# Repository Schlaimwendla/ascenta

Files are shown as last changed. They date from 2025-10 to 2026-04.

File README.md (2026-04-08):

# 🦾👓 Ascenta – Guiding your Vision  

Welcome to **Ascenta** – a smart glasses project designed to **support blind and visually impaired people** in their daily lives.  
This is our **diploma thesis** project, powered by the **Arduino Nicla Vision board** and connected to a mobile app for seamless interaction.  

---

## 🌟 Project Idea  
Ascenta aims to make the world more accessible by combining **computer vision**, **edge AI**, and **wearable technology**:  

- 👓 **Smart Glasses** equipped with the **Nicla Vision** board  
- 📱 **Mobile App** connection for additional features and user control  
- 🧭 Guidance and assistance in daily life activities  
- ❤️ Designed with empathy and inclusivity at its core  

---

## 🛠️ Tech Stack
- **Hardware:** Arduino Nicla Vision (Edge AI, camera, sensors)  
- **Software:** MicroPython / Arduino IDE / Android App  
- **Connectivity:** WiFi - TCP for glasses ↔ app communication  
- **Features in progress:**  
  - Navigation hints  
  - Daily reminders & assistance via app  

---

## 🚀 Vision  
We believe technology should **remove barriers** – not create them.  
With Ascenta, our goal is to bring **independence, safety, and confidence** to visually impaired individuals.  

---

## 📲 About the App  
The companion app serves as a **hub for communication** between the smart glasses and the user:  
- Live feedback  
- Configurable guidance modes  
- Daily assistant (plans, reminders, etc.)  

---

## 📌 Current Status  
Fully finished App and working functionality between App and Glasses

---

## 💡 Why “Ascenta”?  
The name comes from **"ascent"**, symbolizing **rising above limitations**, and **"sentience"**, reflecting **intelligent guidance**.  
Together: **Ascenta – Guiding your Vision**.  

---

## 🤝 Contributing  
This is part of our diploma thesis, but feedback, ideas, and positive vibes are always welcome ✨  

---

## 🏷️ Hashtag  
#ascenta #guidingyourvision #smartglasses #niclavision #diplomarbeit  

---

👓💙 *Ascenta – Guiding your Vision*

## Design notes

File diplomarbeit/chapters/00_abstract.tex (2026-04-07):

% !TEX root = ../main.tex
\cleardoublepage
\chapter*{Abstract}
\markboth{Abstract}{Abstract}
\addcontentsline{toc}{chapter}{Abstract}

This diploma thesis details the development of ``Ascenta'', an intelligent assistive wearable designed to support visually impaired individuals. Given the challenges of navigating complex urban environments, the project aims to create an affordable solution using artificial intelligence to provide information about the user's social surroundings.

The technical framework utilizes the Arduino Nicla Vision microcontroller. The firmware implements the \textbf{F}aster \textbf{O}bjects, \textbf{M}ore \textbf{O}bjects (FOMO) architecture for efficient on-device face detection. For user interaction, a local and privacy-oriented voice recognition system was developed using the Vosk engine within a custom Android application. Communication is established via an optimized TCP protocol to ensure low-latency data streaming between the wearable and the mobile device.

The current implementation successfully recognizes faces within the field of view and determines proximity using Time-of-Flight sensors. The results demonstrate the efficiency of the decentralized architecture and provide a solid foundation for future development of general obstacle detection models.

\cleardoublepage
\chapter*{Kurzfassung}
\markboth{Kurzfassung}{Kurzfassung}
\addcontentsline{toc}{chapter}{Kurzfassung}

Die vorliegende Diplomarbeit dokumentiert die Entwicklung von \glqq Ascenta\grqq, einer intelligenten Assistenzbrille zur Unterstützung sehbeeinträchtigter Personen im Alltag. Angesichts der Komplexität moderner urbaner Umgebungen besteht das Ziel des Projekts in der Realisierung eines kostengünstigen Wearables, das mittels künstlicher Intelligenz Informationen über das soziale Umfeld liefert.

Die technische Umsetzung basiert auf dem Arduino Nicla Vision Mikrocontroller. Die Firmware nutzt die FOMO-Architektur (\textbf{F}aster \textbf{O}bjects, \textbf{M}ore \textbf{O}bjects) zur effizienten On-Device-Gesichtserkennung. Zur Interaktion wurde eine lokale, datenschutzkonforme Sprachverarbeitung auf Basis der Vosk-Engine in einer Android-Applikation implementiert. Die Kommunikation erfolgt über ein optimiertes TCP-Protokoll, um minimale Latenzzeiten beim Datenstreaming zwischen der Brille und dem Smartphone zu gewährleisten.

Das realisierte System ist in der Lage, Personen im Sichtfeld zu identifizieren und die Distanz mittels Time-of-Flight-Sensorik zu bestimmen. Die Ergebnisse belegen die Funktionalität der dezentralen Architektur und bilden die Grundlage für zukünftige Erweiterungen zur allgemeinen Hinderniserkennung.

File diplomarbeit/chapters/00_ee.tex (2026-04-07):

% !TEX root = ../main.tex
\chapter*{Eidesstattliche Erklärung}

\begingroup 
\linespread{1}\selectfont

Es wird an Eides statt erklärt, dass die vorliegende Diplomarbeit selbstständig und ohne fremde Hilfe verfasst, andere als angegebene Quellen und Hilfsmittel nicht direkt benutzt und die benutzten Quellen wörtlich und inhaltlich entnommenen Stellen als solche erkenntlich gemacht wurden.

\vspace{1.5cm}

\noindent
\begin{tabular}{@{}p{5.5cm} p{1cm} p{8.5cm}@{}}
\begin{tabular}{@{}l@{}}
    Braunau, 11.02.2026 \\
    \makebox[5.5cm]{\dotfill} \\
    \small Ort und Datum
\end{tabular} 
& & 
\begin{tabular}{c}
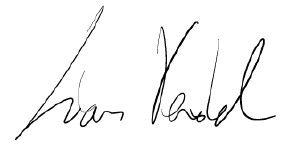
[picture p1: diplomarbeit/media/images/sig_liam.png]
    \smash{\raisebox{-0.4cm}{}} \\
    \makebox[8.5cm]{\dotfill} \\
    \small Liam Vendel
\end{tabular} \\[2.5cm]

\begin{tabular}{@{}l@{}}
    Braunau, 11.02.2026 \\
    \makebox[5.5cm]{\dotfill} \\
    \small Ort und Datum
\end{tabular} 
& & 
\begin{tabular}{c}
    \smash{\raisebox{-0.2cm}{}} \\
    \makebox[8.5cm]{\dotfill} \\
    \small Fabian Lindlbauer
\end{tabular} \\[2.5cm]

\begin{tabular}{@{}l@{}}
    Braunau, 11.02.2026 \\
    \makebox[5.5cm]{\dotfill} \\
    \small Ort und Datum
\end{tabular} 
& & 
\begin{tabular}{c}
    \smash{\raisebox{-0.2cm}{\hspace{-1cm}}} \\
    \makebox[8.5cm]{\dotfill} \\
    \small Manuel Zauner
\end{tabular}
\end{tabular}
\endgroup

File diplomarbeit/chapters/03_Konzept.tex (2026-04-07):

% !TEX root = ../main.tex
\chapter{Konzept}
Dieses Kapitel beschreibt die Architektur zum finalen Konzept des Assistenzsystems \glqq Ascenta\grqq. Es liefert einen detaillierten Gesamtüberblick über das funktionale Zusammenwirken der Teilsysteme und definiert die logischen Verantwortlichkeiten der einzelnen Komponentrn.

\section{Gesamtüberblick und Systeminteraktion}
Das System basiert konzeptionell auf einer dezentralen \glqq Split-Brain\grqq-Architektur, die die Gesamtarbeitslast strategisch auf zwei physisch getrennte, aber logisch eng vernetzte Knotenpunkte aufteilt. Das übergeordnete Ziel dieses Ansatzes ist es, die Hardware direkt am Kopf des Nutzers so leicht, energieeffizient und unauffällig wie möglich zu gestalten. Daher lagert die Architektur die ressourcenintensive Datenverarbeitung und komplexe Entscheidungslogik gezielt auf das ohnehin vorhandene Smartphone des Nutzers aus

Die Interaktion im Gesamtsystem wird durch diese Zweiteilung definiert:
\begin{itemize}
    \item \textbf{Die smarte Brille (Edge-Device):} Sie fungiert in diesem Konstrukt als spezialisierter Sensor-Satellit. Ihre Hauptaufgabe ist die kontinuierliche Erfassung der Umgebungsdaten (visuell, auditiv, räumlich) und die unmittelbare, latenzarme Vorverarbeitung direkt an der Datenquelle (Edge-AI). Anstatt rohe Videoströme zu senden, extrahiert sie lediglich relevante Metadaten und streamt diese bandbreitenschonend an das mobile Endgerät.
    \item \textbf{Das Smartphone (Host-Device):} Es übernimmt die Rolle des leistungsstarken Hauptrechenzentrums. Hier laufen die asynchronen Datenströme der Brille zusammen. Das System fusioniert die eingehenden Sensordaten, verarbeitet und analysiert die Benutzereingaben über Natural Language Processing (NLP) und führt die finale Kontextbewertung durch. Basierend auf dieser Auswertung generiert das Smartphone das situativ passende akustische Feedback.
\end{itemize}

Der detaillierte Informationsfluss zwischen diesen Komponenten wird in den folgenden Abschnitten anhand der spezifischen Datenflussdiagramme für die Use Cases visualisiert (siehe Abbildungen \ref{fig:flow_use_case_a} und \ref{fig:flow_use_case_b}).

\section{Datenfluss der Anwendungsszenarien}
Um das theoretische Zusammenwirken zwischen der Edge-Hardware (Brille) und der zentralen Logik (Smartphone) zu verdeutlichen, wird im Folgenden der Datenfluss für die definierten Kernszenarien (siehe Kapitel \ref{ch:02_use_cases}) dargestellt. Diese Diagramme zeigen die kaskadierende Verarbeitung von der Sensorerfassung bis zur Nutzerinteraktion.

\subsection{Datenfluss zur Kollisionsvermeidung}
Im Szenario der Hinderniserkennung (Use Case A) liegt der Fokus auf minimaler Latenz. Wie in Abbildung \ref{fig:flow_use_case_a} dargestellt, übernimmt die Brille die Vorfilterung der Bilddaten mittels FOMO. Nur wenn eine relevante Entität erkannt wird, erfolgt die Übertragung der Koordinaten und Distanzwerte an das Smartphone, welches die akustische Warnung auslöst.

\begin{figure}[htbp]
    \centering
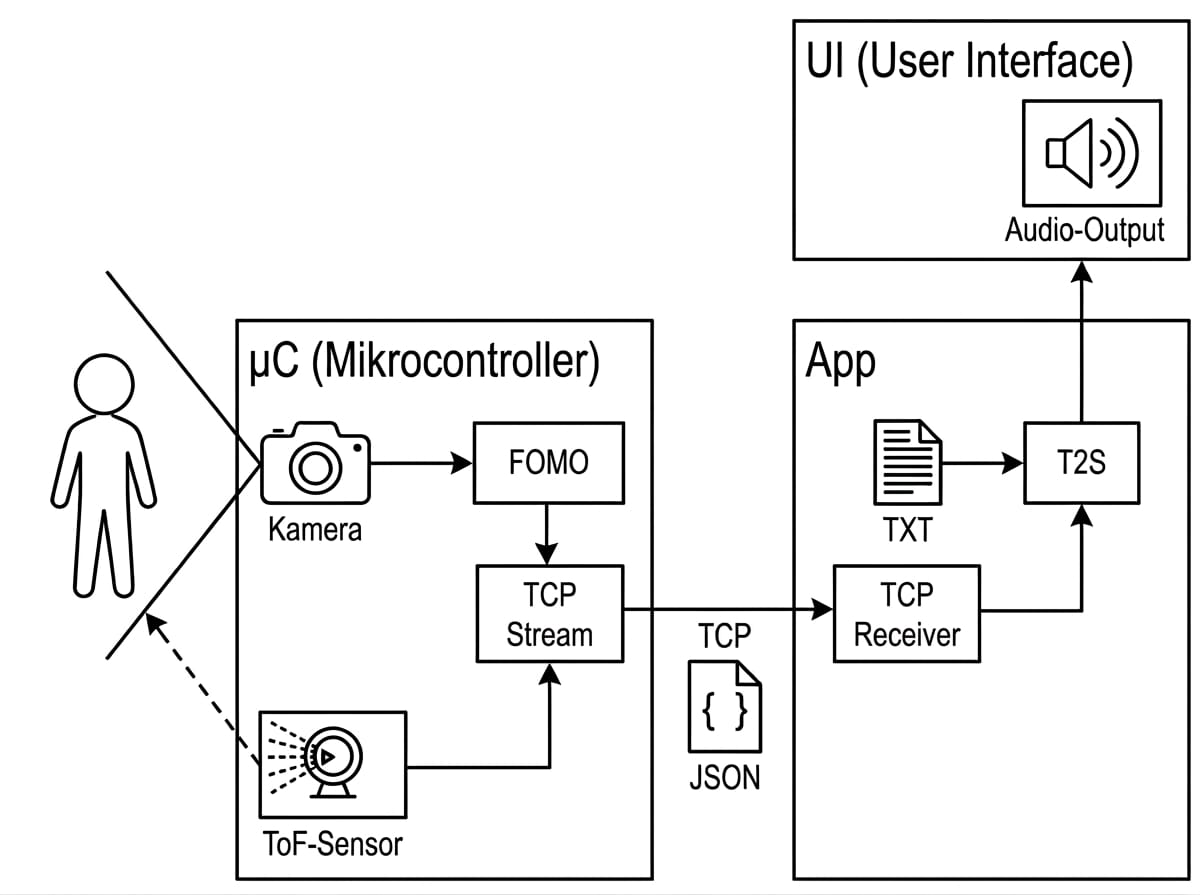
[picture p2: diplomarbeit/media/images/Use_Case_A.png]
    
    \caption{Datenflussdiagramm für Use Case A: Automatische Personenerkennung}
    \label{fig:flow_use_case_a}
\end{figure}

\subsection{Datenfluss der aktiven Umgebungsabfrage}
Bei der gezielten Abfrage durch den Nutzer (Use Case B) wird der Datenstrom um eine auditive Komponente erweitert. Abbildung \ref{fig:flow_use_case_b} zeigt den hybriden Stream: Während die visuellen Daten weiterhin im Hintergrund analysiert werden, wird der Sprachbefehl des Nutzers parallel an die lokale Vosk-Engine zur Interpretation weitergeleitet.

\begin{figure}[htbp]
    \centering
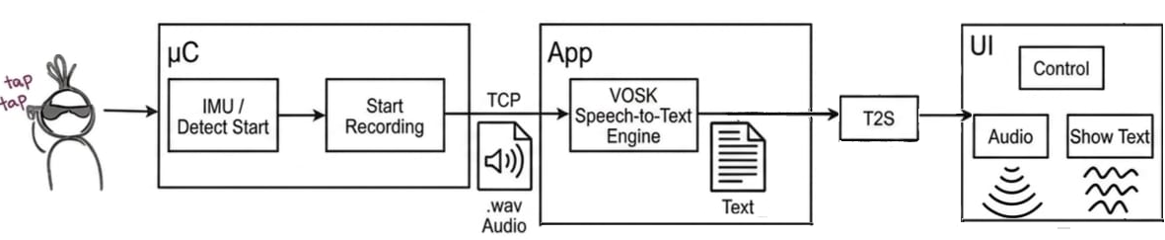
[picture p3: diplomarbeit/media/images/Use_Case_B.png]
    
    \caption{Datenflussdiagramm für Use Case B: Sprachgesteuerte Interaktion}
    \label{fig:flow_use_case_b}
\end{figure}

Die Trennung dieser Pfade stellt sicher, dass zeitkritische Warnungen nicht durch die komplexere Sprachverarbeitung blockiert werden.

\section{Komponenten}
\label{sec:komponenten}
Um den zuvor beschriebenen Datenfluss zu realisieren, setzt sich das Gesamtsystem aus drei wesentlichen logischen Bausteinen zusammen. Diese Säulen sind stark voneinander abhängig und wurden parallel konzipiert, um einen reibungslosen Betriebsablauf zu gewährleisten:

\begin{enumerate}
    \item \textbf{Die physische Struktur (Mechanik und Gehäuse):} Sie bildet das ergonomische Fundament. Sie muss die gesamte Elektronik sicher und unauffällig aufnehmen, eine exakte Ausrichtung der Sensorik garantieren und gleichzeitig die Gewichtsbalance für den Dauereinsatz sicherstellen.
    \item \textbf{Die elektronische Hardware (Sensorik und Energie):} Sie umfasst die physischen Schnittstellen zur realen Welt, primär den Mikrocontroller zur Datenerfassung sowie das autarke Akkumanagement zur mobilen Stromversorgung.
    \item \textbf{Das Software-Ökosystem (Intelligenz und Netzwerk):} Es ist das digitale Bindeglied, welches die rohen Hardware-Signale in verwertbare Informationen übersetzt. Es regelt die asynchrone Kommunikation und beinhaltet die trainierten neuronalen Netze zur Objekt- und Spracherkennung.
\end{enumerate}

\subsection{Software-Ökosystem und Netzwerkkonzept}
\label{sec:konzept_software}
Die Softwarearchitektur teilt sich in die Firmware des Mikrocontrollers und die mobile Applikation. Die Firmware (MicroPython) verantwortet die hardwarenahe Sensorsteuerung und eine erste Datenreduktion (Edge AI mittels FOMO). Die Android-Applikation (Kotlin) dient als unsichtbares Interface (reine Hintergrund-Applikation) und integriert komplexe Algorithmen wie die Offline-Spracherkennung (Vosk) zur auditiven Interaktion.

Der Kern des Konzepts liegt in der asynchronen, herstellerunabhängigen Interaktion zwischen der Brille (Sensorik), dem Kommunikationskanal (WiFi-TCP) und dem Smartphone (Logik und Feedback).

\subsection{Hardware und Elektronik}
\label{sec:konzept_elektronik}

Das hardwareseitige Konzept fokussiert die autonome Energieversorgung sowie eine intuitive Nutzersteuerung des Systems. Die Integration von zwei kompakten LiPo-Akkus mit einer Kapazität von jeweils 620 mAh ermöglicht eine mobile und besonders schlanke Bauweise. Diese Dimensionierung wahrt konzeptionell eine präzise Balance zwischen einem minimalen Platzbedarf und der notwendigen Energie für den Betrieb der KI-Modelle. Durch diesen Aufbau verfügt das System trotz der leichten Bauweise über genügend Leistungsreserven, um sowohl die kontinuierliche Verarbeitung der Sensordaten als auch die Ansteuerung der optischen Rückmeldung zuverlässig zu gewährleisten. Damit entsteht die hardwareseitige Grundlage für ein System, das den Anforderungen an Portabilität und Funktionalität gleichermaßen entspricht.

Zur Steuerung der Hardware nutzt das Konzept einen vibrationsbasierten Sensor als zentrales Bedienelement, welches die direkte Kontrolle über verschiedene Interaktionsmuster ermöglicht. Anstatt eines physischen Tasters detektiert dieser Sensor Klopfzeichen oder Erschütterungen am Gehäuse und wandelt diese in Steuerbefehle um:
\begin{itemize}
    \item \textbf{Systemaktivierung:} Eine einfache Betätigung schaltet das Nicla Vision Modul ein. Diese Hardware-Trennung schont die Kapazität der Akkus in Ruhephasen maßgeblich.
    \item \textbf{Sprachsuche:} Ein schnelles, zweimaliges Drücken (Double-Click) aktiviert die Audioaufnahme, um die Umgebung per Sprachbefehl nach einem bestimmten Gegenstand zu durchsuchen.
\end{itemize}

Um diese sprachgesteuerte Suchfunktion im Alltag praktikabel zu gestalten, sieht der theoretische Entwurf vor, das zugrundeliegende neuronale Netz auf eine Vielzahl von alltagsgebräuchlichen Objekten zu trainieren. Das Modell soll diese Gegenstände im aufgenommenen Bild anschließend zuverlässig identifizieren und lokalisieren.

\subsection{Mechanik und Gehäusedesign}
Im Rahmen der Konzeptphase wurden die grundlegenden Anforderungen und Zielsetzungen für die zu entwickelnde Brille definiert. Ein zentraler Aspekt bestand darin, die notwendige Elektronik unterzubringen, ohne dabei Funktionalität, Tragekomfort und Design zu vernachlässigen.

Der Aufbau des Modells besteht, wie bei herkömmlichen Brillen, aus zwei Brillenbügeln, einem Rahmen und zwei Gläsern als Abdeckung. Letztere sind nicht transparent und decken den Innenraum des Rahmens ab, in welchem die Elektronik verstaut ist.

Der Rahmen weist ein ergonomisches Design auf, das gut an der Stirn und überhalb der Augen anliegt. Nasenpads sorgen zusätzlich für ein angenehmes Sitzen auf der Nase. Die Bügel schließen bündig am Rahmen ab und sind über einen Scharniermechanismus mit diesem verbunden. Ihre ergonomische Form verläuft zunächst leicht nach außen, um im Schläfenbereich ausreichend Platz zu bieten, und verjüngt sich dann schräg nach innen, um hinter dem Ohr sicheren Halt zu gewährleisten. Auf diese Weise umschließt die Brille den Kopf des Benutzers und sorgt für einen stabilen Sitz.

\begin{figure}[H]
    \centering
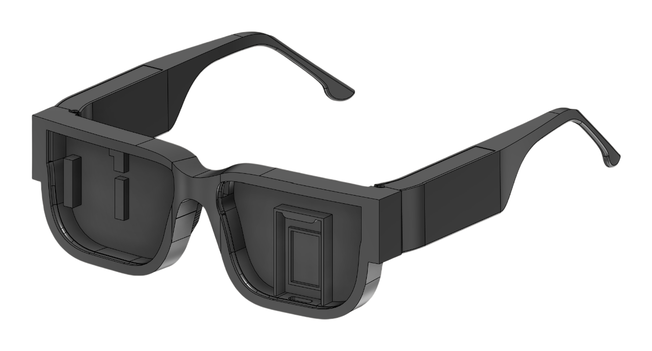
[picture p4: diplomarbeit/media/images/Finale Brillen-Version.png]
    
    \caption{Gesamtansicht der Brille}
    \label{fig:Gesamtansicht der Brille}
\end{figure}

Innerhalb des Rahmens befindet sich links eine Halterung für den Mikrocontroller und rechts eine Halterung für das Lademodul inklusive USB-C-Öffnung. \newline
Die Elektronik wird zusätzlich von den beiden Gläsern in ihrer Position gehalten.

\begin{figure}[H]
    \centering
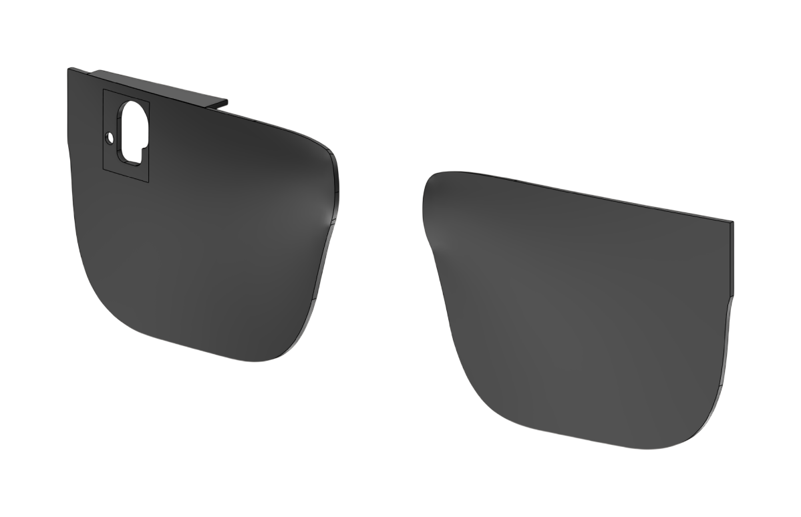
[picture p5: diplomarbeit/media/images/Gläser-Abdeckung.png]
    
    \caption{Gläser-Abdeckung}
    \label{fig:Gläser-Abdeckung}
\end{figure}

In jedem Bügel ist ein Akku untergebracht, der durch eine Abdeckung verborgen wird. Diese lässt sich einfach auf- und zuschieben.

Unterhalb der rechten Ecke des Rahmens befindet sich ein Schalter zum Ein- und Ausschalten der Brille.

Der Scharniermechanismus hält Rahmen und Bügel über einen von oben eingesetzten Pin zusammen und ermöglicht, dass die Brille auf beiden Seiten eingeklappt werden kann.

Durch den 3D-Druck ist die Brille leicht und modular aufgebaut. Alle Bauteile lassen sich einzeln demontieren und wieder zusammenfügen.

\section{Interaktionen}
Die Interaktion zwischen den Systemkomponenten und dem Nutzer verläuft in einem kontinuierlichen Kreislauf, der als asynchroner kaskadierender Prozess aufgebaut ist:

\begin{enumerate}
    \item \textbf{Eingabe-Trigger (Nutzer):} Der Prozess wird durch physisches Doppel-tippen an der Brille initiiert. Dieser Hardware-Interrupt triggert die Audioaufnahme.
    \item \textbf{Lokale Vorverarbeitung \& Edge-AI (Brille):} Das Nicla Vision erfasst Kamera-Frames und Audiodaten. Parallel läuft ein ressourcensparendes Edge-AI-Modell (FOMO) direkt auf dem Mikrocontroller. Es lokalisiert Gesichter oder vordefinierte Objektklassen im Kamerabild und übergibt die Koordinaten an die Vorverarbeitungseinheit.
    \item \textbf{Paketierung und WiFi-Stream:} Der Mikrocontroller paketiert die Sensorrohdaten (Audio-Chunks), die Distanzwerte (ToF-Sensor) und die KI-Koordinaten. Diese Daten werden asynchron in einen TCP-Stream geschrieben und über das lokale WiFi-Netzwerk gesendet.
    \item \textbf{Zentrale Logik \& Datenfusion (Smartphone):} Ein TCP-Socket-Server auf der Android-Applikation empfängt den Datenstrom. Die zentrale Steuerung fusioniert die Rohdaten und nutzt die ToF-Werte, um die relativen Distanzen der ermittelten KI-Koordinaten zu berechnen.
    \item \textbf{Kontextanalyse und Sprachverarbeitung:} Der Audiodatenstrom wird an die Offline-Spracherkennungs-Engine (Vosk) weitergeleitet, die den Sprachbefehl des Nutzers (z.\,B. \glqq Befindet sich jemand vor mir?\grqq) in Text umwandelt. Die Entscheidungslogik gleicht den Sprachbefehl anschließend mit den fusionierten Sensordaten ab.
    \item \textbf{Akustisches Feedback (Ausgabe):} Basierend auf der Analyse generiert das System ein Feedback. Es besteht entweder aus synthetisierter Sprache via Text-to-Speech (z.\,B. \glqq Person in einem Meter Entfernung erkannt\grqq) oder aus Signaltönen. Die Ausgabe erfolgt diskret über den Lautsprecher oder Kopfhörer des Smartphones.
\end{enumerate}

\section{Technisches Design}
Da das System mittels Kamera und Mikrofon sensible Umgebungsdaten erfasst, ist ein striktes Sicherheitskonzept integraler Bestandteil des Entwurfs. Das Konzept verfolgt hierbei den Ansatz des \textit{Privacy-by-Design}. Dies bedeutet, dass der Datenschutz nicht nachträglich aufgesetzt, sondern bereits in der fundamentalen Architektur als Standard verankert ist, indem Datenvermeidung und Offline-Verarbeitung strukturell priorisiert werden.

\subsection{Lokale Datenverarbeitung und Souveränität}
Im Gegensatz zu kommerziellen Smart-Glasses verzichtet \glqq Ascenta\grqq\ konsequent auf Cloud-Schnittstellen für die Kernfunktionen. Die Objekterkennung (FOMO) findet direkt auf dem Mikrocontroller statt, während die Spracherkennung (Vosk) lokal auf dem Android-Endgerät ausgeführt wird. Dies stellt sicher, dass zu keinem Zeitpunkt Videostreams oder private Audiodaten an externe Server übertragen werden. Die Datenhoheit verbleibt vollständig auf der Hardware des Nutzers.

\subsection{Absicherung der Netzwerkschnittstellen}
Durch den Verzicht auf das verbindungslose UDP und den Einsatz des verbindungsorientierten TCP wird die Stabilität der Sitzung erhöht. Da das System in einem lokalen Netzwerk operiert, ist die Angriffsfläche minimiert. Nach dem erfolgreichen Austausch der WLAN-Credentials über BLE wird dieser Kanal für weitere Datenübertragungen geschlossen. Das System nutzt die asynchrone TCP-Struktur, um Telemetrie und Binärdaten klar voneinander zu trennen. Das zugehörige Anwendungsprotokoll stellt jedem Binärpaket einen definierten Präfix inklusive der genauen Byte-Größe voran. Dies verhindert eine Fehlinterpretation von Datenpaketen (Cross-Talk) auf Softwareebene zuverlässig. Die lokale Verschlüsselung des WLAN-Access-Points sorgt zusätzlich dafür, dass Dritte den Datenstrom nicht passiv mitschneiden können.

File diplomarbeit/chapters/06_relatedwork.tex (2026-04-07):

% !TEX root = ../main.tex
\chapter{Verwandte Arbeiten}
\label{ch:related_work}

Dieses Kapitel ordnet das Projekt \glqq Ascenta\grqq\ in das Feld bestehender technischer Lösungen ein und zeigt die unterschiedlichen konzeptionellen Ansätze auf.

\section{Klassische Mobilitätshilfen}
Der weiße Langstock dient der taktilen Erfassung von Bodenhindernissen und Stufen. \glqq Ascenta\grqq\ ist als komplementäres System konzipiert, das durch den Einsatz von Time-of-Flight-Sensorik zusätzliche Informationen über den Raum oberhalb der Gürtellinie liefert, ohne die Funktion des Langstocks zu ersetzen

\section{Smartphone-basierte Applikationen}
Anwendungen wie \textit{Seeing AI} oder \textit{Be My Eyes} nutzen die im Smartphone integrierte Sensorik zur Umgebungsanalyse. Diese Lösungen erfordern die aktive Handhabung des Mobilgeräts. Technisch basieren diese Systeme häufig auf Cloud-Computing-Modellen. \glqq Ascenta\grqq\ verfolgt hingegen einen Wearable-Ansatz mit lokaler Datenverarbeitung (Edge-AI), wodurch die Interaktion freihändig erfolgt und die Funktionalität unabhängig von der Netzabdeckung gegeben ist.

\section{Kommerzielle Standalone-Systeme}
Systeme wie \textit{OrCam MyEye} oder Lösungen auf Basis von \textit{Google Glass} integrieren Kamera und Recheneinheit in einem dedizierten Gehäuse. Diese Geräte sind als spezialisierte Gesamtsysteme konzipiert.

\section{Positionierung von Ascenta}
Das Konzept von \glqq Ascenta\grqq\ unterscheidet sich durch die konsequente Aufteilung der Komponenten (\textit{Split-Brain}). Anstatt alle Rechenprozesse in der Brille zu bündeln, wird das Smartphone als primäre Logikeinheit genutzt. Durch die Verwendung von Standardkomponenten und die lokale Ausführung der Machine-Learning-Modelle (FOMO und Vosk) wird ein System realisiert, das die Datensouveränität durch den Verzicht auf Cloud-Schnittstellen strukturell im Design verankert.

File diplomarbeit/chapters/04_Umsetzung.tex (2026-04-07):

% !TEX root = ../main.tex
\chapter{Umsetzung}
Das vorherige Kapitel definiert das theoretische Konzept. Dieses Kapitel beschreibt die detaillierte praktische Realisierung des Prototyps. Der Fokus liegt hierbei primär auf der softwareseitigen Implementierung der Kernfunktionen. Die Architektur vereint ein ressourcenbeschränktes Embedded-System mit dem asynchronen mobilen Betriebssystem.

\section{Implementierung der Komponenten}
Die konkrete praktische Implementierung der zuvor in Kapitel \ref{sec:komponenten} definierten Systembausteine wird in den folgenden Abschnitten detailliert beschrieben.
\subsection{Software-Architektur und Datenverarbeitung}
\label{sec:software_implementierung}
Die softwareseitige Umsetzung erfordert die Koordination eines ressourcen\-beschränkten Embedded-Systems (MicroPython) und eines mobilen Betriebssystems (Android). Die folgenden Abschnitte erläutern die Lösungsansätze für die Netzwerkkommunikation, die asynchrone Datenverarbeitung und das Speichermanagement detailliert.

\subsubsection*{Entwicklungsumgebungen und Werkzeuge (Toolchain)}
Die softwareseitige Realisierung des \glqq Ascenta\grqq-Projekts erfordert den Einsatz spezialisierter Entwicklungsumgebungen (IDEs), um die unterschiedlichen Anforderungen von Embedded-Systems und mobiler App-Entwicklung effizient zu vereinen.

\textbf{OpenMV IDE für MicroPython (Arduino Nicla Vision)} \\
Für die Programmierung, das Flashen und das Debugging des Arduino Nicla Vision kommt die \textit{OpenMV IDE} zum Einsatz \cite{openmv_ide}. Im Gegensatz zu klassischen C++ basierten Arduino-Umgebungen ist OpenMV exakt auf Machine-Vision-Anwendungen unter MicroPython zugeschnitten. Die Umgebung bietet eine direkte serielle REPL-Schnittstelle (Read-Eval-Print Loop), welche die Ausführung von Skripten in Echtzeit ohne vorherigen Kompilierungszyklus ermöglicht. Ein für die Entwicklung essenzieller Vorteil dieser IDE ist der integrierte Framebuffer-Viewer: Er überträgt das Live-Bild des Kamerasensors direkt über die USB-Schnittstelle auf den PC, was die Kalibrierung des Sichtfeldes massiv erleichtert.

\begin{figure}[htbp]
    \centering
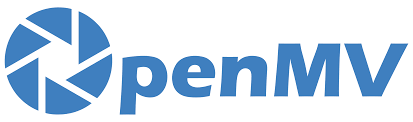
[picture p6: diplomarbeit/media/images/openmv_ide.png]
    
    \caption{Logo der OpenMV IDE}
    \label{fig:openmv}
\end{figure}

\textbf{Android Studio (Kotlin Applikation)} \\
Die Entwicklung der mobilen Applikation erfolgt in \textit{Android Studio}, der offiziellen und von Google empfohlenen Entwicklungsumgebung für das Android-Betriebssystem \cite{android_studio}. Die IDE stellt umfassende Werkzeuge für die Programmierung in Kotlin bereit, darunter den Android Profiler zur Echtzeitanalyse der Netzwerk- und CPU-Auslastung.

\begin{figure}[htbp]
    \centering
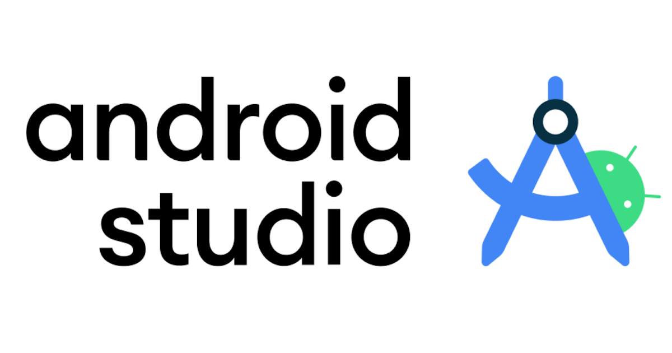
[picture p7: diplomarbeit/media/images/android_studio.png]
    
    \caption{Logo von Android Studio}
    \label{fig:androidstudio}
\end{figure}

\subsubsection*{Projektkonfiguration (Gradle und Manifest)}
Die grundlegende Architektur, das Abhängigkeitsmanagement und die Rechteverwaltung der Android-Applikation werden über zwei zentrale Steuerungsdateien definiert.

\textbf{Abhängigkeitsmanagement (build.gradle.kts)} \\
Das \textit{Gradle-Build-System} automatisiert den Kompilierungsprozess und verwaltet externe Bibliotheken \cite{android_gradle}. In der \texttt{build.gradle.kts} auf App-Ebene wird die minimale Kompatibilität (\texttt{minSdk = 31}) auf Android 12 festgelegt. Dies ist eine bewusste Designentscheidung, da erst ab dieser Version die entkoppelten, modernen Bluetooth-Berechtigungen zur Verfügung stehen. Zudem werden hier die essenziellen Kernbibliotheken importiert, darunter die \textit{Vosk Offline Engine} (\texttt{vosk-android:0.3.47}) für die lokale Spracherkennung sowie \texttt{viewBinding = true} zur typsicheren Anbindung der grafischen XML-Layouts an den Kotlin-Code.

\textbf{Rechteverwaltung und Deklaration (AndroidManifest.xml)} \\
Die Datei \texttt{AndroidManifest.xml} fungiert als Steuerzentrale gegenüber dem Betriebssystem \cite{android_manifest}. Sie registriert die Kernkomponenten der Applikation, primär die \texttt{MainActivity} und den Netzwerk-Dienst (\texttt{AscentaService}). 
Ein kritischer Aspekt ist die Deklaration der Hardware-Berechtigungen (Permissions). Da das System aktiv nach BLE-Geräten sucht und TCP-Verbindungen aufbaut, fordert das Manifest spezifische Netzwerk- und Bluetooth-Rechte an. Ausschlaggebend ist hierbei die Nutzung der neuen Android 12 Bluetooth-Rechte (\texttt{BLUETOOTH\_SCAN} und \texttt{BLUETOOTH\_CONNECT}), welche die feingranulare Kopplung der Brille erlauben. Um den TCP-Stream bei deaktiviertem Bildschirm aufrechtzuerhalten, wird der \texttt{AscentaService} explizit mit dem Attribut \texttt{foregroundServiceType="connectedDevice"} beim System deklariert.

\subsubsection*{Android Lifecycle-Management und Systementkopplung}
Da das Smartphone während der Nutzung der Assistenzbrille typischerweise in der Tasche des Nutzers verbleibt und der Bildschirm deaktiviert ist, neigt das Android-Betriebssystem dazu, Hintergrundprozesse aus Energiespargründen zu terminieren (Doze-Mode). Die Architektur lagert daher die gesamte Netzwerk- und Bluetooth-Logik in den deklarierten \texttt{AscentaService} aus. 

Durch die Eskalation dieses Dienstes zu einem \textit{Foreground Service} priorisiert das Betriebssystem den Prozess dauerhaft auf die höchste Stufe \cite{android_foreground}. Das Android-System verlangt für diese Priorisierung zwingend die Einbindung einer permanenten Benachrichtigung (Notification), welche dem Anwender die aktive Nutzung im Hintergrund signalisiert:

\begin{lstlisting}[language=Java, caption={Start des Foreground Services zur Verhinderung der Terminierung}]
val notification = NotificationCompat.Builder(this, CHANNEL_ID)
    .setContentTitle("Ascenta Assistenzsystem")
    .setContentText("Netzwerkverbindung zur Brille aktiv...")
    .setSmallIcon(R.drawable.ic_eye)
    .setPriority(NotificationCompat.PRIORITY_HIGH)
    .build()

// Zwingt Android, den Service bei Display-Off nicht zu killen
startForeground(1, notification)
\end{lstlisting}

\subsubsection*{Asynchrone BLE-GATT State-Machine}
Das System überträgt die WLAN-Credentials (Provisioning) initial über das Bluetooth Low Energy (BLE) Generic Attribute Profile (GATT) vom Smartphone auf die Brille. Die größte programmiertechnische Herausforderung hierbei ist die stark ereignisgesteuerte, asynchrone API des Android-Bluetooth-Stacks \cite{android_gatt}. Die Applikation implementiert hierfür eine strikte State-Machine innerhalb eines \texttt{BluetoothGattCallback}.

Um Puffer-Überläufe auf dem Bluetooth-Chip des Nicla Vision zu verhindern, darf das System SSID und Passwort nicht simultan senden. Die Kotlin-Logik schreibt zunächst die SSID in die entsprechende Characteristic und wartet zwingend auf den \texttt{onCharacteristicWrite}-Callback mit dem Status \texttt{GATT\_SUCCESS}, bevor das Passwort kaskadierend übertragen wird:

\begin{lstlisting}[language=Java, caption={Kaskadierendes Provisioning der WLAN-Daten via BLE-GATT Callback}]
override fun onCharacteristicWrite(
    g: BluetoothGatt, 
    char: BluetoothGattCharacteristic, 
    status: Int
) {
    if (status == BluetoothGatt.GATT_SUCCESS) {
        if (char.uuid == SSID_CHAR_UUID) {
            // SSID erfolgreich bestaetigt, nun Passwort uebermitteln
            val passChar = g.getService(PROV_SERVICE_UUID).getCharacteristic(PASS_CHAR_UUID)
            passChar.value = pendingPassword!!.toByteArray()
            g.writeCharacteristic(passChar)
            
        } else if (char.uuid == PASS_CHAR_UUID) {
            // Provisioning komplett abgeschlossen
            g.disconnect()
            startTcpConnection() // Einleitung der Hauptkommunikation
        }
    }
}
\end{lstlisting}

\subsubsection*{Evolution der Netzwerkarchitektur (BLE $\rightarrow$ UDP $\rightarrow$ TCP)}
Die finale Implementierung der Netzwerktopologie resultierte aus einer dreistufigen Evaluierungsphase während der Entwicklung. Da das System hohe Anforderungen an Latenz und Datensicherheit stellt, dokumentiert der folgende Prozess die Abwägung und praktische Erprobung verschiedener Protokollstacks.

\vspace{1em}
\noindent\textbf{Phase 1: Das initiale BLE-GATT-Profil} \\
Das ursprüngliche Design sah das Nicla Vision als eigenständiges BLE-Peripheral vor. Das System spannte einen GATT-Server auf, um Daten über spezifische Characteristics zu übertragen. Die Übertragung von Audiodaten (ca. $128.000$ Bytes) stieß jedoch auf massive Barrieren. BLE-Pakete sind im Standard auf eine Payload (MTU) von 20 Bytes limitiert. Um den Hardware-Puffer des Mikrocontrollers zu schützen und einen \texttt{OSError 11} zu vermeiden, musste der Versand künstlich auf 15\,ms Intervalle gedrosselt werden. Dies führte zu inakzeptablen Latenzen von mehreren Sekunden für eine einzige Sprachnachricht.

\begin{lstlisting}[language=Python, caption={Berechnung des Audiospeichers und initiales BLE-Setup}]
# 16000 Hz * 1 Channel * 2 Bytes * 4.0s = 128.000 Bytes Pufferbedarf
TOTAL_BYTES = int(SAMPLE_RATE * CHANNELS * BYTES_PER_SAMPLE * RECORD_SECONDS)
UART_SERVICE_UUID = bluetooth.UUID("6E400001-B5A3-F393-E0A9-E50E24DCCA9E")
\end{lstlisting}

\vspace{1em}
\noindent\textbf{Phase 2: Der Zwischenschritt über das User Datagram Protocol (UDP)} \\
Um die BLE-Limitierung zu umgehen, erfolgte in der Entwicklung der Wechsel auf ein WiFi-basiertes Netzwerk unter Nutzung von UDP. Dieses Protokoll ermöglichte theoretisch eine verzögerungsfreie Übertragung, da es keine Bestätigungszyklen (Acknowledge) erfordert. In der praktischen Erprobung offenbarte UDP jedoch eine kritische Instabilität: \textit{Packet Loss}. In einem mobilen Szenario, in dem sich der Nutzer bewegt, führten verlorene Datenpakete zu korrupten JPEG-Dateien und unvollständigen Audio-Chunks. Da UDP keine Fehlerkorrektur bietet, konnte die Applikation die defekten Binärströme nicht mehr zusammensetzen.

\vspace{1em}
\noindent\textbf{Phase 3: Finale hybride Topologie (BLE \& TCP)} \\
Aufgrund der Unzuverlässigkeit von UDP wechselten wir final zum Transmission Control Protocol (TCP). TCP garantiert durch interne Prüfsummen und automatische Paketwiederholung eine verlustfreie Übertragung. Das System nutzt in der finalen Umsetzung nun eine hybride Strategie: BLE übernimmt ausschließlich die Geräteerkennung und den Austausch der WLAN-Daten (Provisioning). Nach erfolgreichem BLE-Provisioning verbindet sich der Mikrocontroller mit dem WLAN und die App etabliert daraufhin den Hauptdatenstrom über eine verbindungsorientierte TCP-Verbindung (Port 5005). Die Firmware konfiguriert den Socket auf dem Nicla Vision mittels \texttt{setblocking(False)}. Dies verhindert, dass Netzwerkverzögerungen den Mikrocontroller in einen Deadlock versetzen.

\subsubsection*{Stream-Multiplexing und Custom Protocol Parser}
Die Nutzung einer einzigen TCP-Verbindung (Port 5005) für völlig unterschiedliche Datentypen kennzeichnet eine architektonische Besonderheit des Systems. Der Datenstrom (\textit{Stream}) interleavt kontinuierliche Textnachrichten (JSON-Telemetrie) mit großen binären Payloads (JPEG-Bilder, WAV-Audiodaten). 

Ein eigenes Applikationsprotokoll (Application Layer) verhindert eine Vermischung der Datentypen. Der Code stellt binären Übertragungen einen definierten Präfix inklusive Payload-Größe voran (z.\,B. \texttt{AUD\_START:12500}). Der Android \texttt{AscentaService} implementiert einen maßgeschneiderten Parser auf Basis von Kotlin-Coroutines, der den Stream zunächst zeichenweise bis zum Line-Feed (\texttt{\textbackslash n}) ausliest und bei Erkennung eines Binär-Präfixes temporär auf einen blockierenden Byte-Reader umschaltet:

\begin{lstlisting}[language=Java, caption={Kotlin-Coroutine für dynamisches TCP-Stream-Multiplexing und Thread-Switching}]
tcpJob = CoroutineScope(Dispatchers.IO).launch {
    val input = tcpSocket!!.getInputStream()
    while (isActive && isConnected) {
        val line = readLineFromStream(input) // Liest ASCII bis zum Line-Feed \n
        
        if (line.startsWith("IMG_START:")) {
            val size = line.substringAfter(":").toInt()
            // Temporaerer Wechsel auf blockierenden Binär-Reader
            val imgBytes = readBytesFromStream(input, size)
            val bitmap = BitmapFactory.decodeByteArray(imgBytes, 0, imgBytes.size)
            // Synchronisation mit dem Main-Thread fuer UI-Updates
            withContext(Dispatchers.Main) { updateUiWithImage(bitmap) }
            
        } else if (line.startsWith("AUD_START:")) {
            val size = line.substringAfter(":").toInt()
            val audioBytes = readBytesFromStream(input, size)
            processAudioWithVosk(audioBytes)
            
        } else if (line.startsWith("{")) {
            parseTelemetryJson(line) // Uebergabe an Standard JSON-Parser
        }
    }
}
\end{lstlisting}

\subsubsection*{Ausfallsicherheit durch Heartbeat-Mechanismus}
Die Applikation implementiert einen asynchronen Watchdog, um Verbindungsabbrüche zuverlässig zu erkennen. Über den stehenden TCP-Socket sendet die App alle zehn Sekunden einen Ping an die Brille. Bleibt der Response für mehr als 25 Sekunden aus, schließt die Software die Verbindung sicher und reaktiviert den BLE-Discovery-Modus zur automatischen Neuverbindung (\textit{Self-Healing}):

\begin{lstlisting}[language=Java, caption={Heartbeat-Coroutine zur Überwachung der Verbindungsstabilität}]
heartbeatJob = CoroutineScope(Dispatchers.IO).launch {
    while (isActive) {
        if (isConnected) {
            sendCommand("ping")
            delay(10000)
            if (System.currentTimeMillis() - lastPingResponse > 25000) {
                withContext(Dispatchers.Main) {
                    isConnected = false
                    stopHeartbeat()
                    startBleScan() // Zurueck in den Discovery-Status
                }
            }
        } else { delay(5000) }
    }
}
\end{lstlisting}

\subsubsection*{Concurrency und Thread-Sicherheit in Kotlin}
Die Android-Applikation führt netzwerkbasierte I/O-Operationen und rechenintensive Machine-Learning-Prozesse (Vosk) simultan aus. Dafür implementiert der Code ein striktes Thread-Dispatching mittels \textit{Coroutines}. Sämtliche Sockets und blockierende Lesevorgänge operieren ausschließlich im Hintergrund-Thread (\texttt{Dispatchers.IO}). Sobald die Coroutine ein Datenpaket vollständig empfängt, führt sie einen synchronisierten Kontextwechsel zurück auf den Main-Thread durch (\texttt{withContext\allowbreak(Dispatchers.\allowbreak Main)}), um die Benutzeroberfläche zu aktualisieren oder die TTS-Engine konfliktfrei anzusteuern.

\subsubsection*{Ressourcenmanagement und Modell-Integration (Nicla Vision)}
Die Firmware des Nicla Vision (\texttt{firmware.py}) operiert unter extremen Speicherrestriktionen. Von den theoretischen 2 MB RAM des STM32H7-Prozessors steht MicroPython nach dem Bootvorgang lediglich ein nutzbarer Heap von ca. 1 MB zur Verfügung. Dieser begrenzte Speicher muss gleichzeitig den 115 KB großen Framebuffer der Kamera, die Netzwerk-Sockets, die Audio-Puffer sowie die hochkomplexen Tensoren des Machine-Learning-Modells fassen.

Da die dynamische Speicherallokation in MicroPython bei solch starker Auslastung schnell zu Speicherfragmentierung (Heap Fragmentation) führt, was einen Systemabsturz zur Folge hat, wenn kein zusammenhängender Speicherblock für Bild-Tensoren mehr gefunden wird, greift die Architektur auf proaktive Maßnahmen zurück. Die Firmware reserviert initial einen Notfall-Puffer über \texttt{micropython.alloc\_emergency\_exception\_buf(100)}, um Abstürze während hardwarenaher Interrupts abzufangen. Zudem erzwingt der Code eine deterministische Garbage-Collection-Strategie. Der Befehl \texttt{gc.collect()} wird strategisch nach jedem Frame-Snapshot manuell aufgerufen, um nicht mehr referenzierte Objekte sofort zu vernichten und der Fragmentierung entgegenzuwirken.

\subsubsection*{Die Kernschleife der Umgebungserfassung}
Die Hauptmethode \texttt{run\_detection} steuert die kontinuierliche Überwachung der Umgebung. Der Kamerasensor wird auf \texttt{sensor.RGB565} und \texttt{sensor.QVGA} konfiguriert. Ein anschließendes \texttt{windowing((240, 240))} schneidet das Bild exakt auf die benötigte Input-Tensor-Größe zu. Erkennt der Algorithmus ein valides Objekt, konstruiert die Firmware dynamisch einen JSON-String mit Label, Konfidenzwert und Distanz und streamt diesen asynchron über den TCP-Socket:

\begin{lstlisting}[language=Python, caption={Initialisierung des Sensors und Extraktion der Vorhersagewerte}]
def run_detection():
    gc.collect() # Proaktive Defragmentierung
    try:
        sensor.set_windowing((240, 240)) # Exakter Zuschnitt auf Model-Input
        img = sensor.snapshot()
        
        # Inferenz des FOMO-Modells
        result = g_model.predict([img])[0].flatten().tolist()
        best_index = max(range(len(result)), key=lambda i: result[i])
        best_conf = result[best_index]
        
        label_name = LABELS[best_index] if best_index < len(LABELS) else "Unknown"
        distance_mm = tof.read() if tof else 0
        
        del img # Sofortige Freigabe des 115 KB Framebuffers
        gc.collect()
        
        if best_conf >= 0.6:
            json_str = json.dumps({
                "label": label_name,
                "conf": f"{best_conf:.2f}",
                "dist": distance_mm
            }) + "\n"
            send_tcp_packet(json_str.encode())
            
    except Exception as e:
        print(f"Vision Err: {e}")
\end{lstlisting}

\subsubsection*{Auswertung des 4D-Tensors und Sensorfusion}
Die Auswertung der Vorhersagedaten des FOMO-Modells stellt eine besondere algorithmische Herausforderung dar. Das quantisierte Modell generiert einen vierdimensionalen Tensor (Heatmap), der das Bild in ein Grid unterteilt. Die Firmware iteriert über das X/Y-Grid. Findet der Algorithmus ein lokales Maximum über dem Schwellenwert, berechnet die Firmware den absoluten Bildschwerpunkt (Zentroid) und fusioniert die 2D-Bildkoordinaten mit der Z-Achse (Distanz in Millimetern) des ToF-Sensors. Diese fusionierten Raumkoordinaten werden unmittelbar im Anschluss in das JSON-Format serialisiert und asynchron über den TCP-Stream an das Smartphone gesendet. Dort dienen sie der Applikation als Berechnungsgrundlage für die präzise, direktionale Sprachausgabe an den Nutzer.

\subsubsection*{Low-Level Hardware-Kommunikation (I2C \& Registerauslesung)}
Eine verlässliche Batterieanzeige ist für blinde Nutzer essenziell. Die Firmware liest den integrierten Fuel-Gauge-IC (MAX17262) direkt über den I2C-Bus aus. Der Mikrocontroller adressiert den Chip unter der Hexadezimal-Adresse \texttt{0x36} und fordert zwei Bytes ab dem Register \texttt{0x06} (RepSOC) an. Da der Chip die Daten hardwareseitig im \textit{Little-Endian}-Format überträgt, konvertiert die Software die rohen Bytes in einen Integer und dividiert den Wert anschließend durch $256,0$, um den Ladezustand in Prozent zu erhalten:

\begin{lstlisting}[language=Python, caption={Direkte I2C-Registerauslesung des State-of-Charge (SOC) vom MAX17262}]
def get_soc(self):
    if not self.fuel_gauge_i2c: return None
    try:
        # Auslesen von 2 Bytes aus dem RepSOC Register (0x06) des ICs
        data = self.fuel_gauge_i2c.readfrom_mem(0x36, 0x06, 2)
        
        # Konvertierung des Little-Endian Bytearrays zu einem Integer
        soc_raw = int.from_bytes(data, 'little')
        
        # Berechnung des realen Prozentwerts gemaess Datenblatt-Faktor
        return soc_raw / 256.0 
    except:
        return None
\end{lstlisting}

\subsubsection*{Kinetische Interaktionssteuerung (Tap-Detection)}
Zur Freihandbedienung (Aktivierung der Spracherkennung) liest die Firmware den internen 6-Achsen-IMU-Sensor (LSM6DSOX) via I2C aus. Um zuverlässig einen beabsichtigten Doppeltipp (Double-Tap) von der normalen Gehbewegung zu unterscheiden, wertet der Algorithmus den \textit{Ruck} ($\Delta g$) aus.

Überschreitet der kombinierte Beschleunigungsvektor einen empirisch ermittelten Schwellenwert von $1,75$ G, speichert das System den Zeitstempel. Folgt ein zweiter Ausschlag in einem definierten Zeitfenster zwischen 100 und 600 Millisekunden, wird die Aktion als valider Double-Tap registriert und das Kommando an das Smartphone gesendet:

\begin{lstlisting}[language=Python, caption={Filterung von Störbewegungen und Berechnung der Differenz\-beschleunigung}]
x, y, z = self.lsm.accel()
# Berechnung des Rucks (Aenderungsrate der Beschleunigung)
dx = abs(x - self.last_accel[0])
dy = abs(y - self.last_accel[1])
dz = abs(z - self.last_accel[2])
self.last_accel = (x, y, z)

delta_g = dx + dy + dz # Kombinierter Beschleunigungsvektor

if delta_g > 1.75:
    now = time.ticks_ms()
    diff = time.ticks_diff(now, self.last_tap_time)
    
    # Pruefung, ob der zweite Tap im validen 600ms Fenster erfolgte
    if 100 < diff < 600:
        self.send_tcp_packet(b'{"action": "tap"}\n')
        self.req_audio = True 
        self.last_tap_time = 0
    elif diff > 600:
        self.last_tap_time = now # Ersten Tap als Startpunkt setzen
\end{lstlisting}

\subsubsection*{Speichereffizientes Audio-Streaming}
Die kontinuierliche Aufzeichnung von Audiodaten stellt eine hohe Auslastung für den begrenzten Arbeitsspeicher dar. Eine 3,5-sekündige Audioaufnahme bei 16\,kHz beansprucht exakt $112.000$ Bytes. Die Firmware fragmentiert den Puffer daher in Arrays zu je 4096 Bytes. Ein hardware-getriebener Callback füllt diese Chunks iterativ. 

Durch den gezielten Einsatz von \texttt{memoryview} wird eine \textit{Zero-Copy}-Zuweisung erzwungen: MicroPython verschiebt die Audio-Bytes direkt in die vorallozierten Speicheradressen, anstatt bei jeder Zuweisung neuen Arbeitsspeicher anzufordern. Nach Abschluss generiert die Firmware dynamisch einen 44 Byte großen RIFF/WAVE-Header mittels \texttt{struct.pack} und streamt diesen direkt mit den Daten über den TCP-Socket:

\begin{lstlisting}[language=Python, caption={Zero-Copy Speicherzuweisung und dynamische Generierung des WAV-Headers}]
def create_header(data_size):
    # Bytegenaues Packing gemaess der offiziellen WAV/RIFF-Spezifikation
    return struct.pack('<4sI4s4sIHHIIHH4sI', 
                       b'RIFF', 36+data_size, b'WAVE', b'fmt ', 16, 1,
                       config.CHANNELS, config.SAMPLE_RATE, 
                       config.SAMPLE_RATE * config.CHANNELS * 2, 
                       config.CHANNELS * 2, 16, b'data', data_size)

def _audio_callback(self, buf):
    mv = memoryview(buf)
    l = len(mv)
    off = 0
    while l > 0:
        chunk = g_chunks[self.rec_idx]
        space = AUDIO_CHUNK_SIZE - self.rec_offset
        amt = min(l, space)
        
        # Zero-Copy Zuweisung in den pre-allozierten Buffer
        chunk[self.rec_offset : self.rec_offset+amt] = mv[off : off+amt]
        self.rec_offset += amt
        off += amt
        l -= amt
\end{lstlisting}

\subsubsection*{Dynamisches Asset-Management des Akustikmodells}
Ein spezifisches technisches Hindernis unter Android besteht darin, dass kompilierte C++-Bibliotheken (Vosk JNI) keine Dateien direkt aus dem komprimierten APK-Asset-Ordner lesen können. Sie erfordern absolute Dateipfade auf einem unkomprimierten Dateisystem \cite{vosk_api}. Die Applikation löst dieses Problem durch einen asynchronen Entpackungsprozess beim Erststart. Eine IO-Coroutine iteriert rekursiv durch das Modell-Verzeichnis der Assets und kopiert die binären Akustik-Modelle Byte für Byte in den internen \texttt{filesDir}-Speicherbereich des Smartphones.

\subsubsection*{Audio-Verarbeitung und kognitive Entlastung}
Nach der Transkription des Audiosignals oder der Objekterkennung erfolgt die Sprachausgabe über die offizielle \texttt{TextToSpeech}-API von Android \cite{android_tts}. Um den blinden Nutzer nicht mit Dauerwarnungen zu überlasten, implementiert die Applikation eine dynamische Cooldown-Logik. Befindet sich das Objekt in einer unkritischen Distanz (über 100\,cm), wird ein Cooldown von sechs Sekunden für dieses spezifische Label aktiviert. Unterschreitet die vom ToF-Sensor gemessene Distanz jedoch einen kritischen Schwellenwert (z.\,B. unter 40\,cm), greift eine Override-Logik, die den Cooldown ignoriert und eine sofortige Kollisionswarnung erzwingt.

\subsubsection*{I/O-Auslagerung beim Bild-Streaming}
Die Brille bietet zur Verifikation des Sichtfeldes die Funktion, hochauflösende Snapshots an die Smartphone-App zu senden. Ein unkomprimiertes Bitmap belegt jedoch den verbleibenden RAM nahezu vollständig. 

Zur Lösung dieses Speicherengpasses nutzt die Firmware ein klassisches \textbf{Swap-Verfahren} auf dem Dateisystem. Das aufgenommene Bild wird direkt unter Anwendung einer JPEG-Kompression auf den Flash-Speicher der Brille geschrieben (\texttt{temp.jpg}). Unmittelbar danach zerstört die Firmware das rechenintensive Bildobjekt im RAM manuell durch den \texttt{del img}-Befehl und erzwingt eine Garbage-Collection. Erst mit dem nun wieder freien Arbeitsspeicher wird die Datei \texttt{temp.jpg} stückweise ausgelesen und an das Handy gestreamt:

\begin{lstlisting}[language=Python, caption={Verwendung des Flash-Speichers als Swap zur Vermeidung von OOM-Exceptions}]
def process_image(self):
    path = "temp.jpg"
    try:
        img = sensor.snapshot()
        img.save(path, quality=75) # Speichern im Flash
        
        del img       # Manuelle RAM-Freigabe des 115 KB Bitmaps
        gc.collect()  # Zwingende Defragmentierung
        
        size = os.stat(path)[6]
        self.send_tcp_packet(f"IMG_START:{size}\n".encode())
        
        # Speicherschonendes, stueckweises Auslesen der Swap-Datei
        with open(path, 'rb') as f:
            while True:
                chunk = f.read(1024)
                if not chunk: break
                self.send_tcp_packet(chunk)
                
        uos.remove(path) # Temporäre Datei sicher löschen
    except Exception as e:
        print(f"Img Err: {e}")
    finally:
        gc.collect()
\end{lstlisting}

\subsubsection*{Benutzeroberfläche und App-Architektur (GUI als Demonstrator)}
Obwohl das finale Assistenzsystem primär für blinde Nutzer über eine \glqq Zero-UI\grqq\ konzipiert ist, spielt die grafische Benutzeroberfläche der Android-Applikation eine essenzielle Rolle als Entwickler-Dashboard und Demonstrator. Die Architektur folgt strikt dem \textit{Single-Activity-Pattern}. Der Code unterteilt die Bildschirminhalte in modulare \texttt{Fragments}, welche die im \texttt{AscentaService} empfangenen Daten über Main-Thread-Callbacks visualisieren:

\textbf{Das ImageFragment (Visueller Debugger):} \\
Dieses Modul dient der Verifikation des Kamerablickwinkels. Sobald das Flash-Swap-Verfahren der Brille abgeschlossen ist und der TCP-Parser das \texttt{ByteArray} extrahiert hat, decodiert das Fragment die Rohdaten mittels der Android \texttt{BitmapFactory}. Da UI-Updates unter Android ausschließlich im Main-Thread erlaubt sind, nutzt das Fragment eine blockierungsfreie Coroutine-Synchronisation, um das gerenderte Bild in der \texttt{ImageView} anzuzeigen:

\begin{lstlisting}[language=Java, caption={Dekodierung und Main-Thread UI-Update des empfangenen JPEG-Streams im ImageFragment}]
// Wird vom AscentaService aufgerufen, sobald IMG_START-Bytes gelesen wurden
fun updateCameraFeed(imageData: ByteArray) {
    // Wandelt die empfangenen Bytes asynchron in ein Android-Bitmap um
    val bitmap = BitmapFactory.decodeByteArray(imageData, 0, imageData.size)
    
    if (bitmap != null) {
        // UI-Updates zwingend im Main-Thread ausfuehren
        activity?.runOnUiThread {
            binding.cameraFeedImageView.setImageBitmap(bitmap)
            binding.statusText.text = "Snapshot empfangen: ${imageData.size} Bytes"
        }
    }
}
\end{lstlisting}

\textbf{Das AudioFragment (Akustische Transkription):} \\
Da das System Sprachbefehle lokal verarbeitet \cite{vosk_api}, ist ein visuelles Feedback der Audio-Erkennung für die Systemvalidierung unerlässlich. Wenn der Nutzer den Doppeltipp an der Brille ausführt, wird der eingehende WAV-Stream im Service an die Vosk-Engine übergeben. Das \texttt{AudioFragment} empfängt den JSON-String der Transkription und extrahiert den erkannten Text, um ihn für den Entwickler als Live-Log auf dem Bildschirm auszugeben:

\begin{lstlisting}[language=Java, caption={JSON-Parsing der Vosk-Transkription im AudioFragment}]
fun onVoskResultReceived(jsonResult: String) {
    try {
        val jsonObject = JSONObject(jsonResult)
        val recognizedText = jsonObject.optString("text", "")
        
        if (recognizedText.isNotEmpty()) {
            activity?.runOnUiThread {
                binding.transcriptionTextView.append("\nNutzer: $recognizedText")
                binding.scrollView.fullScroll(View.FOCUS_DOWN) // Auto-Scroll
            }
        }
    } catch (e: Exception) {
        Log.e("AudioFragment", "Fehler beim Parsen der Vosk-Antwort", e)
    }
}
\end{lstlisting}

\begin{figure}[htbp]
    \centering
    %\includegraphics[width=0.45\textwidth]{media/images/app_stt_screenshot.png}
    \caption{Die Benutzeroberfläche des AudioFragments zur Live-Validierung der Vosk-Spracherkennung}
    \label{fig:app_stt_ui}
\end{figure}

\textbf{Das InfoFragment (System-Dashboard):} \\
Dieses Modul visualisiert den globalen Systemstatus. Es zeigt in Echtzeit an, ob die TCP-Verbindung stabil ist, listet die IP-Adresse des Nicla Vision und aktualisiert dynamisch den via I2C ausgelesenen Akkustand (SOC). Ein Live-Feed im unteren Bereich listet die eingehenden Telemetriedaten auf, wodurch Entwickler sofort validieren können, welches Label mit welcher Konfidenz detektiert wurde.

\subsection{Schaltungsdesign und Energiemanagement}
\label{sec:elektronik_umsetzung}

Um die elektronischen Herausforderungen zu bewältigen, wurde ein modulares System entwickelt. Das Ziel war eine integrierte Energieversorgung, die das System ohne externe Stromquellen betreibt und dabei kompakt und sicher im Brillengestell verbaut ist.

\begin{figure}[H]
    \centering
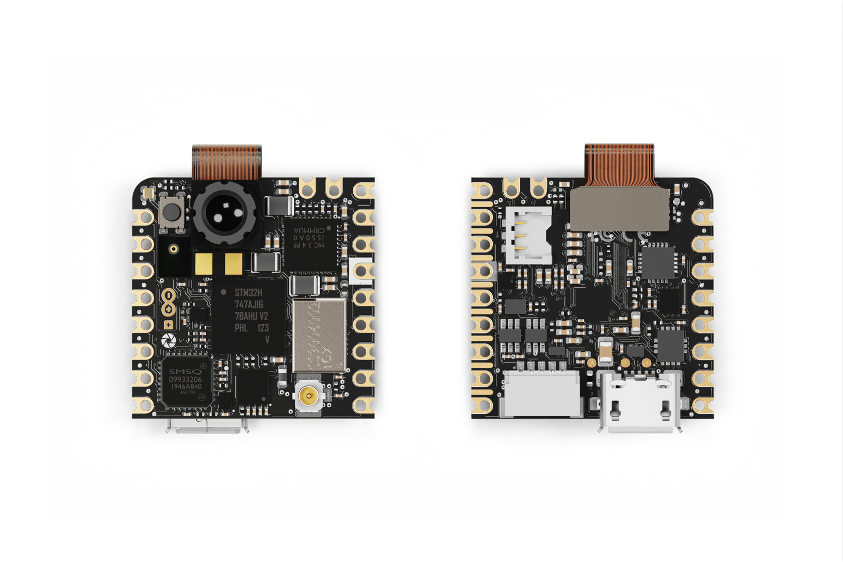
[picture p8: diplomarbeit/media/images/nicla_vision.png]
    
    \caption{Die Vorder- und Rückseite des Arduino Nicla Vision Boards}
    \label{fig:niclavision}
\end{figure}

\subsubsection*{Schaltplan und Erklärung}
Der Schaltplan zeigt die Vernetzung der zentralen Komponenten für das Energiemanagement der Brille.

\begin{figure}[H]
    \centering
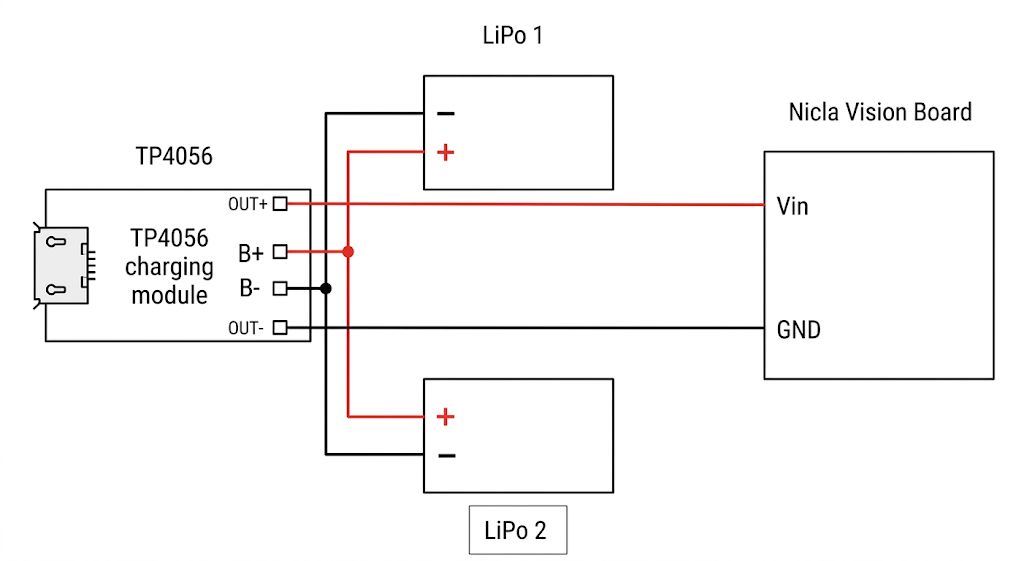
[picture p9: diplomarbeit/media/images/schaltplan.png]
    
    \caption{Schaltplan der zentralen Energieversorgung und Verdrahtung}
    \label{fig:schaltplan}
\end{figure}

Zentrale Verdrahtung:
\begin{itemize}
    \item \textbf{Lademodul (TP4056):} Das Modul bildet das Herzstück der Stromversorgung. Über die Anschlüsse B+ und B- sind die beiden LiPo-Akkus parallel mit dem Laderegler verbunden. Dies ermöglicht es, beide Zellen gleichzeitig über einen einzigen USB-C-Port zu laden.
    \item \textbf{Parallelschaltung der Akkus:} Durch die parallele Verbindung von LiPo 1 und LiPo 2 bleibt die Spannung bei stabilen 3,7\,V, während sich die Kapazität auf insgesamt 1240\,mAh addiert.
    \item \textbf{Versorgung der Nicla Vision:} Die Ausgänge OUT+ und OUT- des Lademoduls führen direkt zur Recheneinheit. Der OUT+ ist mit dem VIN-Pin der Nicla Vision verbunden, während OUT- an GND anliegt.
    \item \textbf{Sicherheitsaspekt:} Durch diese Verschaltung fließt der Strom der Akkus immer zuerst durch das Schutz-Board des TP4056, bevor er die Nicla Vision erreicht. Dadurch ist sichergestellt, dass die empfindliche Elektronik bei einem eventuellen Kurzschluss oder einer zu tiefen Entladung der Akkus sofort vom Stromkreis getrennt wird.
\end{itemize}

\subsubsection*{Schaltungskonzept und Energieversorgung}
Die zentrale Entscheidung beim Schaltungsdesign war die Aufteilung der Energiequelle. Anstatt einen großen, schweren Akku zu verbauen, wurden zwei identische LiPo-Zellen \cite{eemb_akku_620mah} mit einer Kapazität von jeweils 620\,mAh parallelgeschaltet. 
Der wesentliche Vorteil dieser Parallelschaltung besteht darin, dass die Spannung bei nominal 3,7\,V stabil bleibt, was exakt den Betriebsspezifikationen der Nicla Vision entspricht. Gleichzeitig addiert sich die Gesamtkapazität auf 1240\,mAh, sodass die Brille länger genutzt werden kann, ohne dass ein einzelner Akku zu groß für den Brillenbügel wird. Durch diese Aufteilung auf zwei Zellen wird zudem der Entladestrom pro Akku halbiert. Dies verringert die thermische Belastung der einzelnen Zellen und erhöht langfristig die Lebensdauer.

Ein wichtiger Faktor bei der Planung war die Entladecharakteristik der LiPo-Zellen. Wie aus dem typischen Spannungsverlauf (siehe Abbildung \ref{fig:entladungskurve}) ersichtlich wird, fällt die Spannung nach einem initialen Abfall über einen langen Zeitraum nur minimal ab (stabile Entladephase), bevor sie gegen Ende rapide einbricht.

\begin{figure}[H]
    \centering
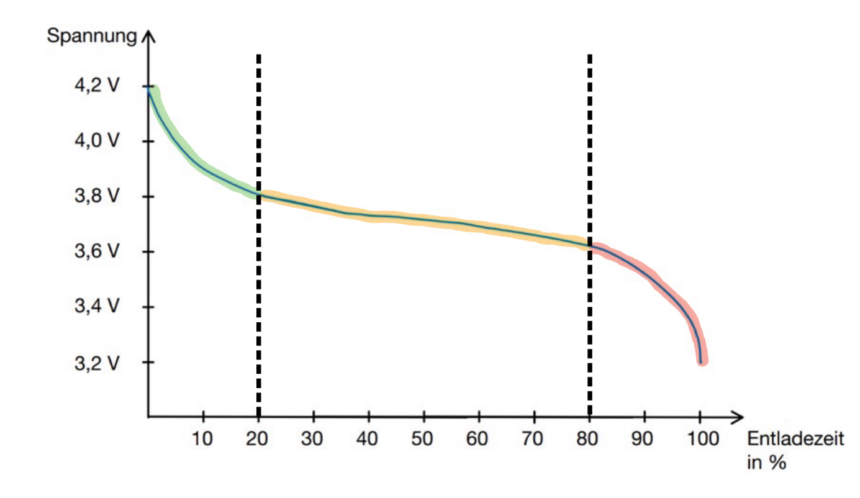
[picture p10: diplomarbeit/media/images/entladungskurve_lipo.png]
    
    \caption{Typische Entladungskurve eines Lithium-Polymer-Akkus}
    \label{fig:entladungskurve}
\end{figure}

Aufgrund dieser flachen Kurve ist es technisch kaum möglich, den exakten Ladezustand (z.\,B. 70\,\% vs. 30\,\%) allein über eine Spannungsmessung zu ermitteln. Um zu verhindern, dass die Brille am kritischen Endpunkt der Kurve ohne Vorwarnung abschaltet, macht sich das System den in die Nicla Vision integrierten Fuel-Gauge-Chip (MAX17262) zunutze. Dieser misst den exakten Stromverbrauch und berechnet die verbleibende Kapazität präzise.

\subsubsection*{Integration des Sicherheitsmanagements}
Um das theoretische Risiko von Akkus in unmittelbarer Kopfnähe zu minimieren, wurde ein TP4056-Lademodul \cite{tp4056_datasheet} als zentrale Kontrollinstanz zwischen die Energiespeicher und die restliche Elektronik geschaltet (siehe Abbildung \ref{fig:tp4056}):
\begin{itemize}
    \item \textbf{Schutzfunktion:} Das Modul überwacht den Stromfluss permanent. Bei einem Kurzschluss oder einer Überlastung trennt es die physische Verbindung zu den Akkus augenblicklich.
    \item \textbf{Laderegelung:} Das Aufladen erfolgt sicher über einen integrierten USB-C-Anschluss. Das Modul steuert exakt, wann der Akku vollständig geladen ist, um eine Überladung zu verhindern. Zudem vereinfacht es den Ladevorgang maßgeblich, da beide Zellen durch die Parallelschaltung gleichzeitig aufgeladen werden können.
\end{itemize}

\begin{figure}[H]
    \centering
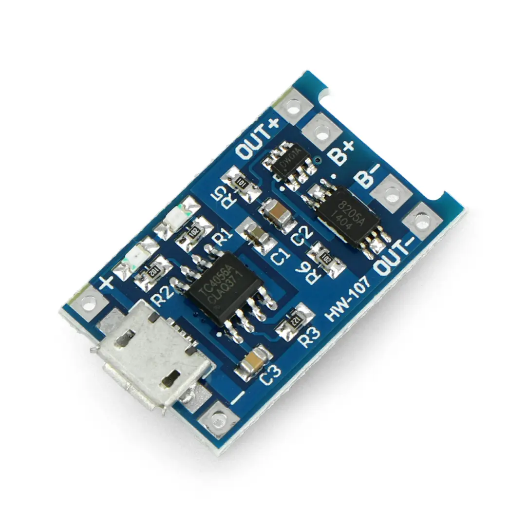
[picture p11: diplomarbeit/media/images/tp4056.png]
    
    \caption{TP4056-Lademodul}
    \label{fig:tp4056}
\end{figure}

\subsubsection*{Lademodul (TP4056)}
Zur sicheren und unkomplizierten Aufladung der Akkus fiel die Wahl auf das TP4056 Lademodul. Da die Brille unabhängig von speziellen Ladegeräten funktionieren soll, stellte ein Modul mit Standard-USB-C-Anschluss die optimale Lösung dar. Das TP4056 ist äußerst kompakt und lässt sich dadurch platzsparend in der Glashalterung platzieren, ohne das Design der Brille zu beeinträchtigen. Es fungiert als zentrale Schnittstelle zwischen einer externen Stromquelle und den internen LiPo-Akkus.

Wichtigste Funktionen für das Projekt:
\begin{itemize}
    \item \textbf{Sicheres Laden:} Das Modul regelt den Ladevorgang nach dem CC/CV-Verfahren. Die Akkus werden zuerst mit konstantem Strom und anschließend mit konstanter Spannung geladen, was die Lebensdauer der Zellen verlängert und Überhitzung verhindert.
    \item \textbf{Tiefentladeschutz:} Eine wesentliche Sicherheitsfunktion ist der Schutz vor Tiefentladung. Das Modul trennt die Verbindung zwischen Akku und Nicla Vision automatisch, bevor die Zellspannung einen kritischen Wert unterschreitet. Dies verhindert dauerhafte Schäden an den empfindlichen LiPo-Akkus.
    \item \textbf{Überlastschutz:} Sollte das System durch einen Fehler zu viel Strom ziehen oder ein Kurzschluss entstehen, schaltet das Modul den Ausgang sofort ab. Da die Elektronik direkt am Kopf getragen wird, ist diese hardwareseitige Sicherung für die Nutzersicherheit unverzichtbar.
\end{itemize}
Integration in das System: Das Lademodul ist so verbaut, dass der USB-C-Port von außen leicht zugänglich bleibt. Von dieser Position aus wird der Ladestrom an beide parallelgeschalteten Akkus verteilt. Gleichzeitig erfolgt die Versorgung der Nicla Vision über den Out-Pin mit der nötigen Betriebsspannung. Durch diese Bauweise wird eine saubere Trennung zwischen dem Ladevorgang und dem eigentlichen Betrieb der Brille realisiert.

\subsection{Entwicklung des Machine-Learning-Modells (Objekterkennung)}
\label{sec:ml_training}

\subsubsection*{Eingesetzte Plattformen}
Für die Datenverarbeitung sowie die Modellentwicklung kamen folgende Plattformen zum Einsatz:
\begin{itemize}
    \item \textbf{Edge Impulse:} Edge Impulse ist eine führende Entwicklungsumgebung für Machine Learning auf Embedded-Geräten (TinyML). Die Plattform ermöglicht den gesamten Workflow von der Datenerfassung über die Merkmalsextraktion bis hin zum Training optimierter Modelle.
    \item \textbf{Roboflow:} Roboflow ist ein spezialisiertes Tool für das Management von Computer-Vision-Datensätzen. Es unterstützt Entwickler dabei, Bilder effizient zu annotieren, zu organisieren und durch Augmentierung künstlich zu erweitern. Zudem bietet es Schnittstellen, um die vorbereiteten Daten direkt in verschiedene Trainings-Frameworks zu exportieren.
    \item \textbf{Kaggle:} Kaggle ist die weltweit größte Online-Community für Data Science und Machine Learning. Die Plattform bietet Zugriff auf eine riesige Auswahl an öffentlichen Datensätzen. Darüber hinaus stellt sie kostenlose cloudbasierte Rechenleistung (GPUs) zur Verfügung, um komplexe Modelle direkt im Browser zu trainieren.
\end{itemize}

\subsubsection*{Architektur des Neuronalen Netzes}
Die Plattform Edge Impulse diente der Konstruktion und dem Training des künstlichen neuronalen Netzes (Convolutional Neural Network, kurz CNN \cite{wikipedia_cnn}). Edge Impulse automatisiert den Aufbau der komplexen Netzstrukturen, greift im Hintergrund jedoch auf die bewährte Schichtarchitektur für die Bildverarbeitung zurück.

\begin{figure}[H]
    \centering
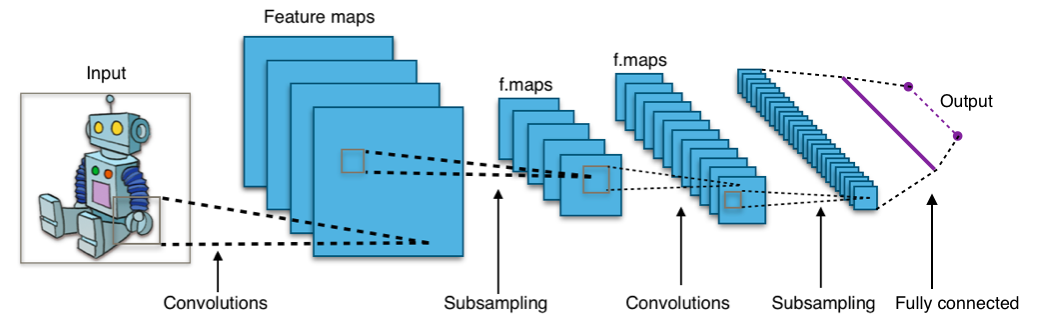
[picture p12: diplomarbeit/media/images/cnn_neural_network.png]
    
    \caption{Prinzipieller Aufbau eines Convolutional Neural Networks (CNN)}
    \label{fig:cnn_architektur}
\end{figure}

Aufbau und Schichtmodell in der Verarbeitungskette: Ein in Edge Impulse definierter \glqq Impulse\grqq\ (eine Daten-Pipeline) übernimmt die schrittweise Analyse der Kamerabilder:
\begin{itemize}
    \item \textbf{Eingabeschicht (Input Layer):} Die Eingabeschicht leitet die Kamerabilder in einer vorab festgelegten, reduzierten Auflösung in das Netz ein.
    \item \textbf{Faltungsschichten (Convolutional Layers):} Das Netz wendet in diesen Schichten verschiedene Filter auf das Bild an. Dieser Prozess extrahiert wichtige visuelle Merkmale wie Kanten, Formen und Texturen.
    \item \textbf{Pooling-Schichten (Subsampling):} Diese Schichten reduzieren die räumlichen Dimensionen der Daten innerhalb des Netzes. Dies senkt die Rechenlast für den Mikrocontroller drastisch und behält ausschließlich die relevantesten Informationen bei.
    \item \textbf{Ausgabeschicht (Output Layer):} Die Ausgabeschicht berechnet abschließend die Wahrscheinlichkeiten für die definierten Objektklassen.
\end{itemize}

Einsatz der FOMO-Architektur (Faster Objects, More Objects): Die Konfiguration in Edge Impulse nutzt explizit die FOMO-Architektur. Dieses Framework wurde speziell für leistungslimitierte Hardware wie die Nicla Vision konzipiert.
\begin{itemize}
    \item \textbf{Klassifizierung statt Regression:} Das Verfahren verzichtet bewusst auf die rechenintensive Berechnung von Bounding Boxes (Rechtecken um die Objekte).
    \item \textbf{Grid-basierte Erkennung:} Der FOMO-Algorithmus teilt das Kamerabild in ein Raster auf. Anschließend bewertet das neuronale Netz für jede Zelle einzeln, welches Objekt sich dort mit welcher Wahrscheinlichkeit befindet.
    \item \textbf{Effizienz und Deployment:} Dieser Ansatz erzielt eine enorm hohe Verarbeitungsgeschwindigkeit. Nach dem Training stellt ein direkter Export aus Edge Impulse das fertige Modell als quantisierte TensorFlow Lite Datei (.tflite) bereit, was eine nahtlose Ausführung auf der Hardware der Brille ermöglicht.
\end{itemize}

\subsubsection*{Modelltraining und Parameterkonfiguration}
Nach der Vorverarbeitung der Bilddaten startet in Edge Impulse der eigentliche Trainingsprozess des neuronalen Netzes. Eine gezielte Anpassung der Hyperparameter stellt dabei ein optimales Gleichgewicht zwischen Erkennungsgenauigkeit und Ressourceneffizienz her.

Konfiguration der Trainingsparameter:
\begin{itemize}
    \item \textbf{Trainingszyklen und Lernrate:} Die Festlegung der Epochen (Training cycles) auf 60 gibt dem Algorithmus ausreichend Durchläufe, um die visuellen Muster zu erlernen. Gleichzeitig vermeidet dieser Wert ein sogenanntes \glqq Overfitting\grqq\ (Auswendiglernen der Trainingsdaten). Eine definierte Lernrate (Learning rate) von 0,001 passt die internen Gewichtungen des Netzes in kleinen, präzisen Schritten an.
    \item \textbf{Validierungsset:} Eine gezielte Aufteilung reserviert 20\,\% des gesamten Datensatzes ausschließlich als Validierungsset. Dieses Vorgehen überprüft die reale Performance des Modells kontinuierlich an Bildern, die das Netz im laufenden Training noch nicht gesehen hat.
    \item \textbf{Batch-Größe:} Die definierte Batch-Größe (Batch size) von 32 führt dem Netz jeweils exakt 32 Bilder gleichzeitig zu, bevor der Algorithmus die internen Gewichtungen aktualisiert.
\end{itemize}

\begin{figure}[H]
    \centering
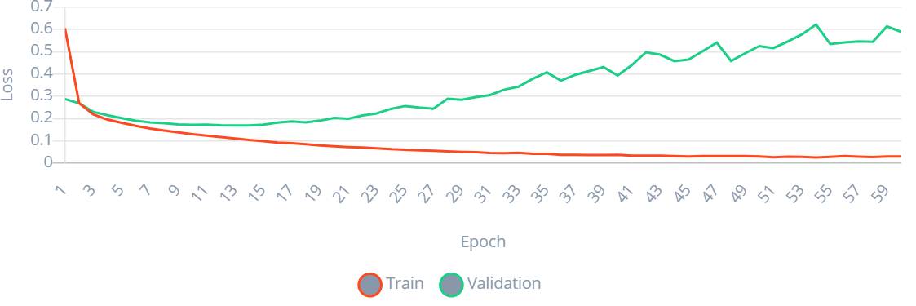
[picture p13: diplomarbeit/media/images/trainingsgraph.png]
    
    \caption{Verlauf des Verlustes (Loss) über die Trainings-Epochen}
    \label{fig:trainingsgraph}
\end{figure}
\newpage
Spezifikation der Netzwerkarchitektur:
\begin{itemize}
    \item \textbf{Eingabeschicht (Input layer):} Die Eingabeschicht speist exakt 172.800 Features in das neuronale Netz ein. Diese Zahl resultiert direkt aus der gewählten Auflösung und den Farbkanälen der übergebenen Bilddaten.
    \item \textbf{Basis-Modell (Backbone):} Die Architektur nutzt das FOMO-Framework auf Basis eines MobileNetV2 0.35 Modells. Diese spezifische Struktur arbeitet extrem leichtgewichtig und optimiert die Rechenabläufe speziell für Mikrocontroller.
    \item \textbf{Ausgabeschicht (Output layer):} Die Konfiguration richtet die letzte Schicht gezielt darauf aus, exakt eine Klasse (1 class) auszugeben. Das neuronale Netz konzentriert sich durch diese Limitierung ausschließlich auf die Erkennung des definierten Zielobjekts.
\end{itemize}

Optimierung für den Mikrocontroller: Die gezielte Aktivierung der Option \glqq Profile int8 model\grqq\ in den erweiterten Einstellungen bereitet das Modell bereits während der Konfiguration auf die nachfolgende Quantisierung vor. Diese Maßnahme garantiert eine speichereffiziente Übertragung des resultierenden Modells im 8-Bit-Format auf den Flash-Speicher der Brille. Mit diesen Spezifikationen wurde nach dem Training ein F1-Score von 80\,\% erreicht.

\begin{figure}[htbp]
    \centering
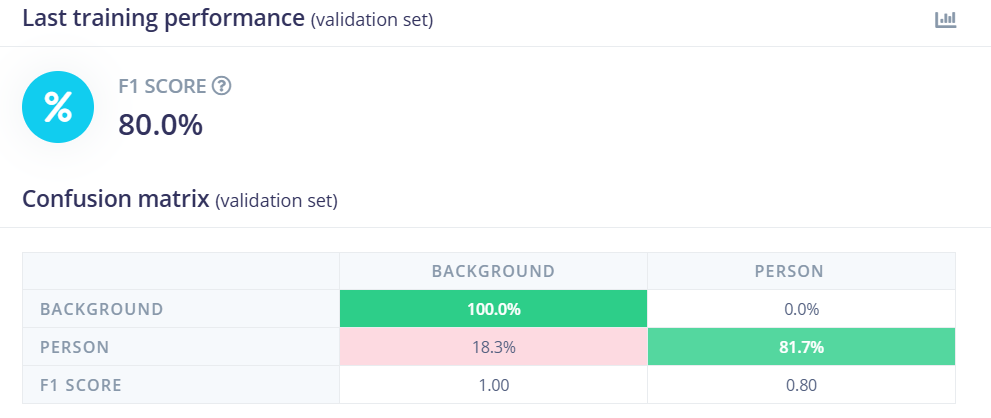
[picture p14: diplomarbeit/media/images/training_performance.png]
    
    \caption{Validierte Trainingsperformance mit einem F1-Score von 80.0\%}
    \label{fig:training_performance}
\end{figure}
\newpage
\subsubsection*{Deployment und Integration in OpenMV}
Nach dem erfolgreichen Training und der Validierung überträgt der Bereitstellungsprozess das fertige Modell auf die Hardware der Nicla Vision. 

Deployment-Prozess:
\begin{itemize}
    \item \textbf{Modell-Export:} Die Auswahl der Zielplattform OpenMV im Bereich \glqq Deployment\grqq\ des Edge Impulse Studios startet den Exportvorgang. Daraufhin generiert und kompiliert die Plattform ein anwendungsbereites Paket.
    \item \textbf{Dateistruktur:} Die Extraktion des heruntergeladenen Pakets liefert zwei essenzielle Dateien: das quantisierte neuronale Netz als .tflite-Datei (TensorFlow Lite) sowie eine Textdatei (labels.txt), welche die Namen der trainierten Objektklassen enthält.
    \item \textbf{Hardware-Transfer:} Die dauerhafte Ablage dieser Dateien im Speicher der Nicla Vision schließt den Datentransfer ab und bildet die technische Voraussetzung, um die Hauptsoftware der Objekterkennung zu starten.
\end{itemize}

\subsubsection*{Softwareseitige Validierung}
Die nachfolgende Analyse schlüsselt die Code-Passagen und ihre technischen Funktionen detailliert auf.

\textbf{Sensor-Konfiguration und Bildvorbereitung:} Vor der Dateneinspeisung in das neuronale Netz passt die Initialisierung die Kamera exakt an die Vorgaben des Modells an.
\begin{lstlisting}[language=Python, caption={Initialisierung und Konfiguration des Kamerasensors}]
sensor.reset()
sensor.set_pixformat(sensor.RGB565)
sensor.set_framesize(sensor.QVGA)
sensor.set_windowing((240, 240))
sensor.skip_frames(time=2000)
\end{lstlisting}
Die Konfiguration setzt die Grundauflösung zunächst auf QVGA (320x240 Pixel). Da das FOMO-Modell ein quadratisches Eingangsformat verlangt, schneidet der Befehl \texttt{sensor.set\_windowing} das Bild aktiv auf 240x240 Pixel zu. Abschließend gibt der Parameter \texttt{skip\_frames} der Kamera 2000 Millisekunden Zeit, um den Weißabgleich und die Belichtung an die Umgebung anzupassen.

\textbf{Dynamisches Speichermanagement:} Der limitierte Arbeitsspeicher (RAM) der Nicla Vision erzwingt einen effizienten Umgang mit den Ressourcen.
\begin{lstlisting}[language=Python, caption={Laden des TFLite-Modells mit dynamischer Speicherprüfung}]
net = ml.Model("trained.tflite", load_to_fb=uos.stat('trained.tflite')[6] > (gc.mem_free() - (64*1024)))
\end{lstlisting}
Der Code lädt die Modelldatei .tflite direkt in das System. Der Parameter \texttt{load\_to\_fb} (Load to Framebuffer) entscheidet dabei dynamisch über den Speicherort. Eine logische Prüfung weist das System an, das Modell nur dann in den regulären RAM zu laden, wenn danach noch eine Sicherheitsreserve von 64 Kilobyte frei bleibt. Dies verhindert Systemabstürze während der rechenintensiven Bildverarbeitung.

\textbf{Post-Processing und die Heatmap-Übersetzung:} Das neuronale Netz liefert keine fertigen Koordinaten, sondern eine vierdimensionale Matrix (Heatmap) mit Wahrscheinlichkeiten. Die Post-Processing-Routine übersetzt diese Matrix in greifbare Objektdaten.
\begin{lstlisting}[language=Python, caption={Konvertierung der Modell-Ausgabe und anschließende Bloberkennung}]
img = image.Image(outputs[0][0, :, :, i] * 255.0)
blobs = img.find_blobs(threshold_list, x_stride=1, y_stride=1, area_threshold=1, pixels_threshold=1)
\end{lstlisting}
Eine Schleife iteriert durch die Ausgabe-Schichten des Netzes. Die Multiplikation der rohen Wahrscheinlichkeitswerte des quantisierten Modells mit 255.0 erzwingt durch die gezielte Fließkomma-Operation ein gültiges Datenformat für die OpenMV-Bibliothek. Dieser Schritt wandelt die Datenmatrix in ein virtuelles Graustufenbild um und nutzt die \texttt{find\_blobs}-Funktion, um die dichtesten Pixel-Zentren (die erkannten Objekte) zu isolieren.

\textbf{Die Hauptschleife:} Die Endlosschleife führt die eigentliche Erkennung durch und erzeugt ein visuelles Feedback.
\begin{lstlisting}[language=Python, caption={Iteration über die Erkennungsergebnisse und Visualisierung}]
for i, detection_list in enumerate(net.predict([img], callback=fomo_post_process)):
if i == 0: continue  # Ignoriert die Hintergrund-Klasse
if len(detection_list) == 0: continue

for x, y, w, h, score in detection_list:
center_x = math.floor(x + (w / 2))
center_y = math.floor(y + (h / 2))
img.draw_circle((center_x, center_y, 12), color=colors[i])
\end{lstlisting}
Der Sensor erfasst kontinuierlich neue Kamerabilder und übergibt sie über \texttt{net.predict} an das neuronale Netz. Das Programm ignoriert die Klasse "0", da diese standardmäßig den Hintergrund repräsentiert. Für jedes valide Objekt berechnet der Algorithmus den geometrischen Mittelpunkt und zeichnet einen farbigen Kreis in das Live-Bild, um die Funktionalität optisch direkt am Bild zu verifizieren.

\begin{figure}[htbp]
    \centering
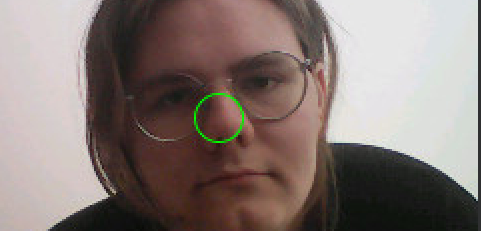
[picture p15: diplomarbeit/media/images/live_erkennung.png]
    
    \caption{Visuelles Feedback der Objekterkennung über den gezeichneten Kreis}
    \label{fig:live_erkennung}
\end{figure}

\subsection{Konstruktion und 3D-Druck}
\label{sec:3ddruck_umsetzung}

\subsubsection{Modellierung des Rahmens und der Abdeckung}
\subsubsection*{Rahmen v1 - 2 und Abdeckung v1 - 2}
Für die Festlegung der Dimensionen wurden gängige Brillenformen sowie ergonomische Standardmaße und Proportionsverhältnisse im Internet \cite{brillen_standardabmessungen} recherchiert.

Die Rahmenkonstruktion basiert auf einer in der zweidimensionalen Ebene definierten
Grundform.

\begin{figure}[H]
    \centering
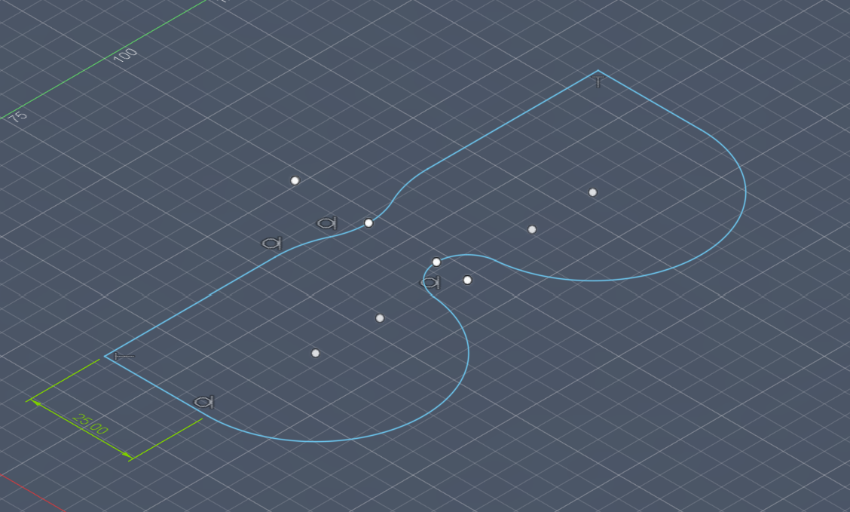
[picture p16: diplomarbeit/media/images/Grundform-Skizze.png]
    
    \caption*{Grundform-Skizze}
    \label{fig:Grundform-Skizze}
\end{figure}

Die Grundplatte wurde an den Rändern nach oben extrudiert, um im Innenraum
ausreichend Platz für die Integration der Elektronik zu gewährleisten. Zusätzliche Öffnungen an den oberen Enden links und rechts wurden vorgesehen, um die Kabelverbindungen in die Bügel zu führen.

Die Abdeckung wird durch die Extrusion des inneren Rahmenbereichs mit einer Höhe von 1 mm erzeugt und auf einer im Rahmen vorgesehenen Erhöhung abgestützt. Über Aussparungen an den linken und rechten Ecken wird sie zusätzlich fixiert.

Elektronik: Im linken Bereich des Rahmens befindet sich das Nicla-Board. Über jeweils eine Aussparung für Kamera, Distanzsensor und Mikrofon in der Brillen-Abdeckung bleibt die wichtigste Sensorik frei.
Im rechten Bereich der Brille ist das Lademodul untergebracht. Unterhalb davon befindet sich eine USB-C-Öffnung für den Anschluss, über welche die Akkus aufgeladen werden können.

Farbliche Kennzeichnung der Nicla Vision-Auflage (rot) und des Lademoduls (orange):

\begin{figure}[H]
    \centering
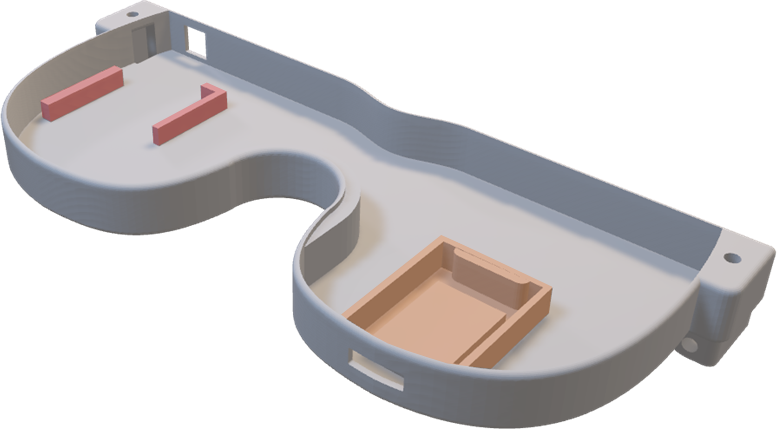
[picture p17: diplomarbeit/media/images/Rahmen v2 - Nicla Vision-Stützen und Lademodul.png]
    
    \caption*{Rahmen v2: Innenraum}
    \label{fig:Rahmen v2: Innenraum}
\end{figure}

Um zu versichern, dass der Mikrocontroller fixiert ist, wird dieser von unten durch Halterungen abgestützt und von oben durch eine entsprechende Ausbuchtung in Position gehalten:

\begin{figure}[H]
    \centering
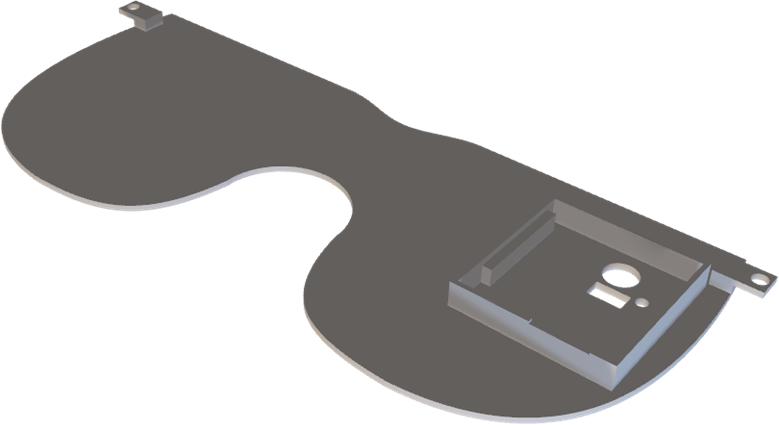
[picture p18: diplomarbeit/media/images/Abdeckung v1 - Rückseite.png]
    
    \caption*{Abdeckung v1: Rückseite mit Nicla Vision-Ausbuchtung}
    \label{fig:Abdeckung v1: Rückseite mit Nicla Vision-Ausbuchtung}
\end{figure}

An den beiden Enden der Abdeckung, links und rechts, sind Vorsprünge mit Löchern angebracht, um die Abdeckung mit dem Rahmen zu verbinden.

Die Position eines Buttons wurde auf der Oberseite des Rahmens oberhalb des Mikrocontrollers gewählt, da diese Anordnung die Verkabelung erleichtert - im Gegensatz zu einer möglichen Platzierung am Bügelende hinter dem Ohr.

\begin{figure}[H]
    \centering
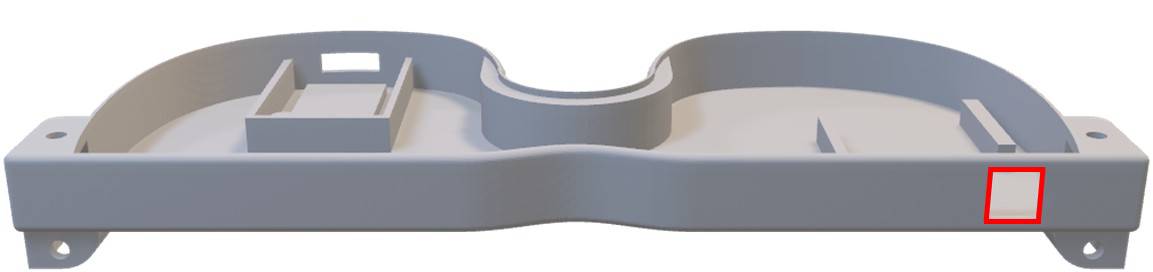
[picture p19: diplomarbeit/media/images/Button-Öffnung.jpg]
    
    \caption*{Rahmen v2: Button-Öffnung}
    \label{fig:Rahmen v2: Button-Öffnung}
\end{figure}

\phantomsection
\label{sec:rahmen_v1-2}
Scharniermechanismus: Zur Gewährleistung einer stabilen, zuklappbaren Verbindung mit den Brillenbügeln wurden an den linken und rechten Enden der Unterseite des Rahmens Ausbuchtungen angebracht.
Die Fixierung der Brillenbügel erfolgt über dünne Pins, die in die vorgesehenen Aussparungen der Ausbuchtungen eingesetzt werden. Gleichzeitig dienen die Ausbuchtungen als stabile Auflagefläche für die Bügel.
Bei der Konstruktion wurde zudem die interne Kabelführung berücksichtigt, sodass ausreichend Platz für die Kabel vorhanden ist, die zum Lademodul im Inneren geführt werden. Dies bleibt auch im zugeklappten Zustand der Brille gewährleistet.

\subsubsection*{Rahmen v3}
Um ein komfortables Tragen der Brille im Nasenbereich zu ermöglichen, wurden die Brillen-Gläser provisorisch verkleinert, wodurch mehr Platz im inneren Bereich geschaffen wurde:

\begin{figure}[H]
    \centering
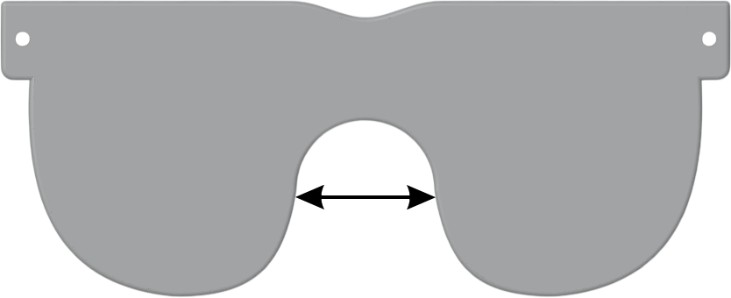
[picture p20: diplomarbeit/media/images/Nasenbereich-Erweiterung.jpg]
    
    \caption*{Rahmen v3: Nasenbereich-Erweiterung}
    \label{fig:Rahmen v3: Nasenbereich-Erweiterung}
\end{figure}

Vorgesehene Umsetzungen:
\begin{itemize}
    \item Die Abdeckung weicht derzeit noch zu stark von der Ästhetik einer Brille ab und verfügt über keine separaten Brillen-Gläser.
    \item Die Form ist aufgrund des unausgewogenen Verhältnisses zwischen Höhe und Breite überarbeitungsbedürftig.
    \item Der Button weist derzeit noch keine Auflagefläche auf und sitzt daher nur lose in der entsprechenden Aussparung.
    \item Im Nasenbereich ist der Tragekomfort durch ergonomisch geformte Nasenpads zu verbessern.
\end{itemize}

Realisierte Verbesserungen:
\begin{itemize}
    \item Erweiterung der Stützen, um die Abdeckung stabiler im Rahmen zu halten.
    \item Abrundung der Kanten des Rahmens, um den Tragekomfort zu erhöhen.
    \item Verbesserung der Lademodul-Halterung (im ersten Testdruck fielen die Maße noch zu schmal aus).
\end{itemize}

\begin{figure}[H]
    \centering
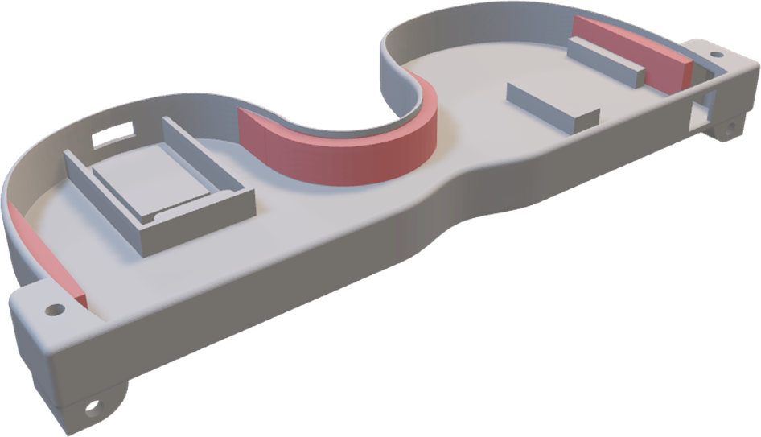
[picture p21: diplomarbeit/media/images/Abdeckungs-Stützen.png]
    
    \caption*{Rahmen v3: Abdeckungs-Stützen}
    \label{fig:Rahmen v3: Abdeckungs-Stützen}
\end{figure}

Durch einen 3D-Druck der Brille konnte ein Konstruktionsproblem identifiziert werden: Der Abstand zwischen der Scharnier-Aussparung und der Rückwand des Rahmens reichte nicht aus, um den vorgesehenen Zuklapp-Radius zu gewährleisten.

\subsubsection*{Rahmen v4}

In der Rahmen-Version 4 wurden mehrere Optimierungen umgesetzt, um die Funktionalität der Brille zu verbessern.
Die zuvor fehlenden Auflageflächen für den Button wurden nun unterhalb der Öffnung integriert:

\begin{figure}[H]
    \centering
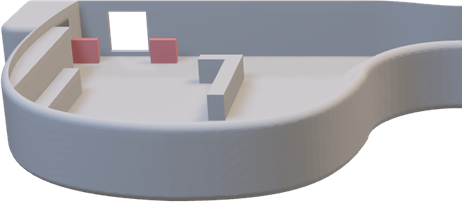
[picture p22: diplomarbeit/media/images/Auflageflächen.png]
    
    \caption*{Rahmen v4: Button-Auflageflächen}
    \label{fig:Rahmen v4: Button-Auflageflächen}
\end{figure}

Im Vergleich zur Vorversion wurden die zuvor vorhandenen Öffnungen an den äußeren Enden links und rechts zur Verbindung der Abdeckung wieder geschlossen. Stattdessen kommt eine Haken-Einrastfunktion zum Einsatz, die eine sichere und ästhetische Verbindung zwischen Abdeckung und Rahmen gewährleisten soll.
\newline
\begin{figure}[H]
    \centering
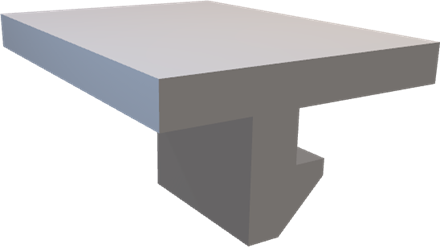
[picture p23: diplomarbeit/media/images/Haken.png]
    
    \caption*{Haken v1: Angebracht an der Abdeckung}
    \label{fig:Haken v1}
\end{figure}

\begin{figure}[H]
    \centering
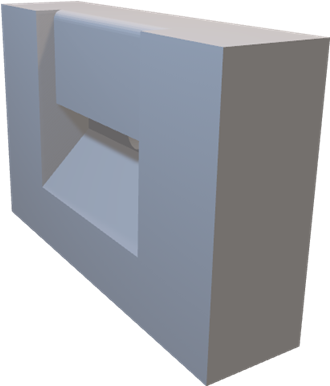
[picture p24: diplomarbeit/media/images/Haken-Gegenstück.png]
    
    \caption*{Haken-Gegenstück v1: Angebracht im Rahmen}
    \label{fig:Haken-Gegenstück v1}
\end{figure}

Einrastmechanismus: Beim Einsetzen wird der Haken von oben in die abgerundete Öffnung des Haken-Gegenstücks eingeführt. Durch seine Biegsamkeit rastet er in der vorgesehenen Position ein, wodurch die Abdeckung passgenau fixiert wird.
Zum Lösen der Verbindung wurde an der Rückseite des Gegenstücks eine kleine Aussparung integriert. Durch dieses kann ein dünner Stab eingeführt werden, um den Haken aus seiner Position zu lösen. Anschließend lässt sich die Abdeckung abnehmen.
  
Ergebnis: Der 3D-Drucker konnte die sehr kleinen Details der Haken-Einrastfunktion nicht präzise umsetzen. Eine Vergrößerung war jedoch nicht möglich, da diese Funktion in den Ecken des Rahmens untergebracht werden sollte, wo zugleich genügend Raum für die Kabelführung zur Verfügung stehen muss. Folglich war eine neue Lösung erforderlich.

\phantomsection
\label{sec:rahmen_v4}
Scharnier-Optimierung: Aufgrund unzureichender Funktionalität des zuvor verwendeten Scharniermechanismus wurde eine alternative Ausführung (\cite{scharnier_vorlage}) des Scharniers montiert (kompatibel mit Bügel v5):

\begin{figure}[H]
    \centering
    
    \caption*{Rahmen v4: Hinteransicht}
    \label{fig:Rahmen v4: Hinteransicht}
\end{figure}

Der Mechanismus besteht aus zwei identischen Bauteilen, die jeweils entgegengesetzt an Rahmen und Bügel montiert werden. Eine Seite bildet das Einsteckelement, die gegenüberliegende Seite das passende Gegenstück. Durch das Zusammenstecken der beiden Teile entsteht ein gelenkartiger Mechanismus, der das Zuklappen der Bügel ermöglicht.

Fazit zu Version 4: Nach dem 3D-Druck des Bauteils stellte sich heraus, dass das Scharnier zu klein dimensioniert war und der Drucker die erforderlichen Feinheiten nicht mit ausreichender Genauigkeit umsetzen konnte.
Zwar wurden Auflageflächen für den Button ergänzt, die übrigen, unter Rahmen v3 beschriebenen Probleme blieben jedoch bestehen beziehungsweise teilweise traten neue auf. Folglich war ein kompletter Neuanfang des Rahmenmodells erforderlich, bei dem die gewonnenen Erkenntnisse aus den bisherigen Versionen angewandt werden sollen.

\subsubsection*{Rahmen v5 - Neukonzeption}
\label{ch:rahmen_v5}

Im Zuge des Neuentwurfs des Rahmen-Designs wurden mehrere zentrale Aspekte berücksichtigt, die in den vorherigen Versionen noch nicht ausreichend umgesetzt werden konnten. Ziel war es, eine ergonomische Form zu entwickeln, die sich an den Proportionen herkömmlicher Brillen orientiert und gleichzeitig für möglichst viele Gesichtsformen geeignet ist.

\begin{figure}[H]
    \centering
    
    \caption*{Rahmen v5: Vorderansicht}
    \label{fig:Rahmen v5: Vorderansicht}
\end{figure}

  Darüber hinaus sollte der bereits zuvor entwickelte Scharniermechanismus grundsätzlich beibehalten, jedoch größer dimensioniert werden, um den Einschränkungen durch die geringe Druckgenauigkeit des 3D-Drucks bei sehr kleinen Bauteilen entgegenzuwirken ($\rightarrow$ kompatibel mit Scharnieren der Bügelversionen 6 bis 9). Zusätzlich wurde vorgesehen, zwei Nasenpads in das Modell zu integrieren, um die Auflage und den Tragekomfort zu verbessern.

\begin{figure}[H]
    \centering
    
    \caption*{Rahmen v5: Hinteransicht mit Nasenpads}
    \label{fig:Rahmen v5: Hinteransicht mit Nasenpads}
\end{figure}

Ein weiterer Ansatz bestand darin, die bisherige Abdeckung zu überarbeiten und, ähnlich wie bei herkömmlichen Brillen, in zwei separate Bereiche für die Gläser aufzuteilen.

\begin{figure}[H]
    \centering
    
    \caption*{Gläser-Abdeckung v1: Vorderansicht}
    \label{fig:Gläser-Abdeckung v1: Vorderansicht}
\end{figure}

Die Konstruktion des Rahmens basiert auf einer Skizze der Augenrand-Oberlinie (siehe Schritt 1 in Abbildung „Rahmen v5: Arbeitsschritte der Konstruktion“). Diese wird nach oben extrudiert, wodurch eine dünne Grundfläche entsteht, aus der die eigentliche Brillenform herausgearbeitet wird.

\begin{figure}[H]
    \centering
    
    \caption*{Rahmen v5: Arbeitsschritte der Konstruktion}
    \label{fig:Rahmen v5: Arbeitsschritte der Konstruktion}
\end{figure}

Zur Gewährleistung der Funktionalität der Brille werden die freien Flächen der Rahmen-Rückseite verschlossen, um die erforderlichen Halterungen im Innenraum platzieren zu können. Die Nicla Vision-Halterung sowie die Lademodul-Halterung stammen aus der vorherigen Rahmenversion und werden mit der Rückseite verbunden. Zur Verschließung der Vorderseite bei gleichzeitig guter Zugänglichkeit wird entlang der beiden Gläser eine Einkerbung integriert, in welche die Abdeckungen eingeführt werden können. Diese entstehen aus den freien Flächen der Rahmen-Vorderseite und werden beim linken Glas durch das Gegenstück der Nicla Vision-Halterung ergänzt.

\begin{figure}[H]
    \centering
    
    \caption*{Rahmen v5: Gläser-Einkerbung}
    \label{fig:Rahmen v5: Gläser-Einkerbung}
\end{figure}
  
Im Zuge der Konstruktion wurden die Aussparungen für Kamera- und Distanzsensor miteinander verbunden und zusätzlich abgerundet, um die optische Gestaltung zu verbessern.

\begin{figure}[H]
    \centering
    
    \caption*{Gläser-Abdeckung v2: Vorderseite}
    \label{fig:Gläser-Abdeckung v2: Vorderseite}
\end{figure}

Weitere umgesetzte Anpassungen:
\begin{itemize}
\item Integration des USB-C-Ports für das Lademodul
\item Integration eines Kabeldurchlasses zwischen linker und rechter Brillenseite
\end{itemize}

\subsubsection*{Rahmen v6}
In der sechsten Version wurden neue, kompaktere Nasenpads implementiert, die im Vergleich zur vorherigen Version weiter oben positioniert sind, wodurch der Tragekomfort erhöht wird. Beide Nasenpad-Versionen wurden im Form-Modus von Fusion 360 modelliert, welcher die Erstellung organisch geformter Bauteile durch direktes Ziehen an Kanten, Flächen und Punkten ermöglicht.

\begin{figure}[H]
    \centering
    
    \caption*{Nasenpad-Vergleich}
    \label{fig:Nasenpad-Vergleich}
\end{figure}

Die Scharniere wurden an der Oberseite um eine glatte Auflage erweitert, welche den Mechanismus stabilisiert und somit während des 3D-Drucks zu einer verbesserten Druckqualität beiträgt.
\par
Zusätzlich wurde an den äußeren Enden des Rahmen-Innenraums eine Kabeldurchführung in die Bügel integriert. Diese ermöglicht die Verbindung der im Rahmen untergebrachten Elektronik mit den in den Bügeln platzierten Akkus.
\par
Um die Gläser-Abdeckungen formschlüssiger in den Rahmen einzusetzen, wird deren Maßstab angepasst. Das linke Glas, das die Nicla Vision-Abdeckung trägt, lässt sich innerhalb von Fusion nur schwer dimensionieren, ohne die Größe der Aussparungen und Ausbuchtungen zu verändern. Daher erfolgt die Anpassung temporär im Open-Source-Grafikprogramm Blender, das eine präzisere Bearbeitung einzelner Punkte, Kanten und Flächen ermöglicht. Zur Bearbeitung des 3D-Modells in Blender wurde dieses aus Fusion als STL-Datei exportiert. STL-Dateien wandeln 3D-Modelle in eine Liste aus Dreiecken um. Beim Import in Blender entstehen dadurch sehr viele Punkte, Kanten und Flächen, was die Komplexität des Modells erhöht. Dadurch kann leichter ein Open-Mesh-Error auftreten, ein Fehler, der im Slicer vor dem 3D-Druck erkannt wird und dazu führen kann, dass das Modell nicht druckbar ist.

\subsubsection*{Rahmen v7}
Der in Abschnitt (\ref{sec:modellierfehler_nasensteg} Mechanische und geometrische Restriktionen) erläuterte Modellierfehler lässt sich durch die folgenden sechs Schritte korrigieren:

\begin{figure}[H]
    \centering
    
    \caption*{Nasensteg-Modellierfehler: Korrekturmaßnahmen}
    \label{fig:Nasensteg-Modellierfehler: Korrekturmaßnahmen}
\end{figure}

\begin{enumerate}
    \item Ausgangslage: Die Vorderseite des Nasenbereichs weist eine ungleichmäßige, verkantete Form auf und muss angepasst werden.
    \item Löschen aller Flächen, die die problematische Vorderseite betreffen.
    \item Auswahl der äußeren Kanten der ausgeschnittenen Fläche: Extrusion dieser Kanten entlang der y-Achse.
    \item Abschneiden der überstehenden, extrudierten Fläche mittels Extrusion-Funktion von oben nach unten, um die gewünschte runde Form zu erzielen.
    \item Erneute Auswahl der äußeren Kanten: Erstellung einer Fläche zwischen diesen Kanten.
    \item Kombination der neu erstellten Fläche mit dem bestehenden Rahmen, wodurch der Volumenkörper wieder geschlossen wird und keine offenen Flächen verbleiben.
\end{enumerate}
\par
Der dargestellte Prozess in der Abbildung verlief nicht vollständig linear. Er war geprägt von Einschränkungen durch Fusion 360, begrenzten Freiheiten bei der Behebung des Modellierfehlers sowie wiederkehrenden Fehlermeldungen während der Anpassungen.
\par
Bei genauerer Betrachtung der Brille fällt eine feine Kante auf, die von Fusion 360 automatisch generiert wurde. Für eine möglichst glatte und angenehme Ausführung der Brille, wird diese Kante noch abgerundet:

\begin{figure}[H]
    \centering
    
    \caption*{Nasensteg-Modellierfehler: finaler Korrekturschritt}
    \label{fig:Nasensteg-Modellierfehler: finaler Korrekturschritt}
\end{figure}

Das linke Abdeckungsglas liegt formschlüssig auf dem Nicla Board auf. Zur Verbesserung der Kabelführung sowie zur Erleichterung des Anschlusses der mitgelieferten Antenne wird die Halterung auf der Rückseite der Abdeckung geringfügig modifiziert.

\begin{figure}[H]
    \centering
    
    \caption*{Abdeckung v5: Rückseite}
    \label{fig:Abdeckung v5: Rückseite}
\end{figure}

\subsubsection*{Rahmen v8}
Während der parallel ablaufenden Konstruktion von Rahmen und Bügel wurde ein neuer Scharniermechanismus integriert. Um zunächst einen einheitlichen Übergang vom Rahmen zum Bügel zu gewährleisten, wurden zwischen der siebten und achten Rahmen-Version die Ecken erweitert:

\begin{figure}[H]
    \centering
    
    \caption*{Vergrößerung der Ecken}
    \label{fig:Vergrößerung der Ecken}
\end{figure}

\phantomsection
\label{sec:rahmen_v8}
Die Konstruktion des Scharniermechanismus basiert auf einer Skizzenebene mit zwei Kreisen unterschiedlicher Radien - einem kleineren und einem größeren. Aus dieser Geometrie wird ein hohl ausgeführter Zylinder gebildet.

\begin{figure}[H]
    \centering
    
    \caption*{Rahmen v8: Scharniermechanismus}
    \label{fig:Rahmen v8: Scharniermechanismus}
\end{figure}

Das Gegenstück wird am Bügel angebracht und besteht aus zwei hohl ausgeführten Zylindern, einem oberen und einem unteren, die die Konstruktion umfassen. Übereinanderliegend entsteht eine gemeinsame Aussparung, durch die von oben ein Pin zur Befestigung geführt wird. Da der unterste Zylinder an seiner Basis geschlossen ist, wird der Pin sicher umfasst.

Um den Zuklappradius zu optimieren, ist die Ummantelung des Zylinders nach innen offen gestaltet.

\subsubsection*{Rahmen v9}
Ein 10 × 2,5 × 5~mm (L × B × H) großer Schalter wurde im Rahmen angebracht. Um den begrenzten Raum optimal zu nutzen, erfolgte die Platzierung unterhalb der Rahmen-Ecken, wo noch ungenutzter Platz vorhanden war:

\begin{figure}[H]
    \centering
    
    \caption*{Rahmen v9: Schalter-Implementierung}
    \label{fig:Rahmen v9: Schalter-Implementierung}
\end{figure}

Drei Bohrungen wurden modelliert, um die Pins des Schalters mit der internen Elektronik zu verbinden. Außerdem wurde die Kabelführung in zwei separate Öffnungen aufgeteilt. Siehe Nahansicht in Abbildung „Rahmen v9: Schalter-Implementierung“: Scharnier-Aussparung (oben) und Akku-Aussparung (unten).

\subsubsection*{Rahmen v10 - finale Version}
Bei einem Praxistest der Brille wurde festgestellt, dass sich die Rückseite des Rahmens hinter dem Auflademodul stark erwärmt, weshalb die Auflagefläche der Halterung verkleinert wurde:

\begin{figure}[H]
    \centering
    
    \caption*{Rahmen v10: Lademodul-Auflagefläche}
    \label{fig:Rahmen v10: Lademodul-Auflagefläche}
\end{figure}
  
Darüber hinaus wurden Länge und Tiefe der Schalter-Öffnung optimiert, sodass der Schalter formschlüssig fixiert ist. Die Bohrungen wurden zudem vergrößert und von drei auf zwei reduziert.

\subsubsection{Modellierung des Bügels}
\subsubsection*{Bügel v1 - 2}

Der erste Entwurf des Bügels war ein stark vereinfachtes Modell, das dazu diente ein Gefühl für den notwendigen Innenraum sowie den Komfort des Bügels zu bekommen. Mit einer durchgehenden Dicke von ca. 10 mm ist das Bauteil für einen Brillenbügel deutlich zu massiv, was sich in Verbindung mit der geradlinigen Form negativ auf das Tragegefühl auswirkte.

\begin{figure}[H]
    \centering
    
    \caption*{Bügel v1: Hinteransicht}
    \label{fig:Bügel v1: Hinteransicht}
\end{figure}

Um im Bügel einen Lithium-Ionen-Akku unterbringen zu können, wurde die Vorderseite vorerst frei gelassen.

\begin{figure}[H]
    \centering
    
    \caption*{Bügel v1: Vorderansicht}
    \label{fig:Bügel v1: Vorderansicht}
\end{figure}

Mit einem 3D-gedruckten Testbauteil konnten folgende Probleme festgestellt werden:
  
\begin{itemize}
    \item Der Platz im Gehäuse für die Akkus war nicht ausreichend (Akku-Maße: 56 mm x 34,5 mm x 10,3 mm). Während Höhe und Breite passend realisiert wurden, war der Bügel-Hohlraum in der Länge noch zu kurz.
    \item Der Bügel konnte noch nicht mit dem Rahmen verbunden werden, da keine Aussparung für die Scharnier-Verbindung vorhanden war.
    \item Durch die sehr geradlinige Form wirkt das Design klobig. Während die Geometrie im vorderen Bereich die notwendige Breite von 10,3 mm aufweist, sollte der hintere Bereich schmaler gestaltet werden, um wie bei herkömmlichen Brillen bequem über dem Ohr zu sitzen.
\end{itemize}

Aufgrund dessen wurde die erste Version entsprechend überarbeitet:

\begin{figure}[H]
    \centering
    
    \caption*{Bügel v2: Hinteransicht}
    \label{fig:Bügel v2: Hinteransicht}
\end{figure}

Der zweite Entwurf beinhaltet folgende Optimierungen:
\begin{itemize}
    \item Ausreichende Gehäuse-Länge für den Lithium-Ionen-Akku.
    \item Schmaleres Bügel-Ende 
\end{itemize}

Bestehen gebliebene Probleme:
\begin{itemize}
    \item Bügel-Ende weiterhin überdimensioniert
    \item Scharniermechanismus zwischen Rahmen und Bügel noch nicht vollständig implementiert
\end{itemize}

Zudem wies der in der Abbildung markierte Übergang noch Optimierungsbedarf auf:

\begin{figure}[H]
    \centering
    
    \caption*{Bügel v2: Seitenansicht}
    \label{fig:Bügel v2: Seitenansicht}
\end{figure}

Der Übergang dient rein ästhetischen Zwecken und weist dahinter lediglich einen ungenutzten Hohlraum auf. Dieser Bereich könnte für die Verbesserung des Tragekomforts genutzt werden. Die verbleibenden 35 mm zwischen Übergang und Bügel-Ende sind für die meisten Personen nicht ausreichend dimensioniert. Aus diesem Grund wurde beschlossen, das Bügelkonzept grundlegend zu überarbeiten und neu zu entwickeln.

\par
Akku-Aufbewahrung: Für die Energieversorgung wird ein Lithium-Ionen-Akku mit einer Kapazität von 2000\,mAh eingesetzt, um eine möglichst lange Betriebsdauer ohne erneutes Aufladen zu gewährleisten. Zur Vermeidung einer ungleichmäßigen Gewichtsverteilung wird im zweiten Bügel ebenfalls ein weiterer Akku untergebracht.

\subsubsection*{Bügel v3 - 4}
In der dritten Version des Bügels wurde der hintere Bereich, der auf dem Ohr aufliegt, gezielt ergonomisch angepasst. Dafür erhielt der Bügel eine nach innen gerichtete Einkerbung, um sich besser an die natürliche Form des Ohres anzupassen. Dadurch werden sowohl der Sitz als auch der Tragekomfort im Vergleich zu den vorherigen Versionen verbessert.

\begin{figure}[H]
    \centering
    
    \caption*{Bügel v3: Seitenansicht}
    \label{fig:Bügel v3: Seitenansicht}
\end{figure}

Zwischen der dritten und vierten Version veränderte sich die Bügelform leicht, wobei der Fokus ausschließlich auf ästhetischen Aspekten lag, ohne die Funktionalität zu beeinträchtigen.

Scharniermechanismus: Zur Umsetzung des in Abschnitt „\nameref{sec:rahmen_v1-2}“ beschriebenen Scharniermechanismus wurden an den Bügel-Enden der dritten Version entsprechende Aussparungen angelegt. Aufgrund unzureichender Funktionalität wurde der Scharniermechanismus in der vierten Version jedoch wieder verworfen, um in einer späteren Version einen überarbeiteten Ansatz zu realisieren.

\subsubsection*{Bügel v5 - 7}
In der fünften Version wurde das Gegenstück des im Abschnitt „\nameref{sec:rahmen_v4}“ beschriebenen Scharniermechanismus integriert. In Version 6 vergrößerte sich das Scharnier, während Version 7 die Stabilität des Scharniers durch eine einheitliche Auflagefläche erhöhte. Beide Anpassungen zielten darauf ab, eine höhere Druckgenauigkeit zu erzielen.

\begin{figure}[H]
    \centering
    
    \caption*{Bügel v7: Scharnier-Auflagefläche (Kennzeichnung in rot)}
    \label{fig:Bügel v7: Scharnier-Auflagefläche}
\end{figure}

\subsubsection*{Bügel v8 - 9}
Aufgrund unzureichenden seitlichen Spielraums im Bereich der Schläfen wird die Vorderseite des Rahmens abgeschrägt. Diese Anpassung erhöht die seitliche Flexibilität der Brille nach außen und ermöglicht dadurch eine bessere Anpassung an unterschiedliche Kopfformen.

\begin{figure}[H]
    \centering
    
    \caption*{Bügel v9: Oberansicht}
    \label{fig:Bügel v9: Oberansicht}
\end{figure}

Zusätzlich wird die Öffnung für den Akku von der Vorderseite auf die Oberseite des Rahmens verlagert und mit einem neuen Verschließmechanismus versehen. Dieser besteht aus zwei schmalen, links und rechts angeordneten Einkerbungen, in welche eine passgenaue Abdeckung eingeschoben werden kann. Dadurch wird ein sicherer Halt der Abdeckung gewährleistet, während gleichzeitig eine einfache Zugänglichkeit zum Akku erhalten bleibt. \newline
Zudem wird an der Vorderseite eine kleine Öffnung integriert, die die Durchführung von Kabeln ermöglicht.

\begin{figure}[H]
    \centering
    
    \caption*{Bügel v9: Nahansicht der Einkerbungen}
    \label{fig:Bügel v9: Nahansicht der Einkerbungen}
\end{figure}

Mit einem Testruck wurde festgestellt, dass das Problem der zu eng anliegenden Bügel weiterhin bestand. Aufgrund der Abmessungen der Akkus ergab sich eine unübliche Bügelhöhe, die den Tragekomfort einschränkte. Daher wurde beschlossen, neue, kompaktere Akkus zu verwenden und auf dieser Basis eine Neukonzeption der Bügel, einschließlich eines überarbeiteten Scharniermechanismus, zu modellieren.

\subsubsection*{Bügel v10 - Neukonzeption}

Der Wechsel auf kompaktere Akkus (620 mAh statt 2000 mAh) ermöglichte eine deutliche Reduzierung des Bügel-Designs. Gleichzeitig konnte die Bügelform so angepasst werden, dass sie eine leichte Biegung nach außen aufweist, wodurch der seitliche Spielraum im Bereich der Schläfen erhöht wurde.

\begin{figure}[H]
    \centering
    
    \caption*{Bügel v10: Seitenansicht}
    \label{fig:Bügel v10: Seitenansicht}
\end{figure}

Zusätzlich wurde der überarbeitete Scharniermechanismus aus Abschnitt „\nameref{sec:rahmen_v8}“ implementiert, der sowohl ein unauffälligeres Design als auch eine verbesserte Funktionalität bietet.

\begin{figure}[H]
    \centering
    
    \caption*{Bügel v10: Scharniermechanismus}
    \label{fig:Bügel v10: Scharniermechanismus}
\end{figure}
  
Ein Vergleich der beiden Akkus verdeutlicht den erheblichen Größenunterschied (von 56 x 34,5 x 10,6 mm $\rightarrow$ 42 x 20,5 x 8,8 mm). Die dadurch einhergehende Verkürzung der Laufzeit wird durch das optimierte Bügel-Design und den erhöhten Tragekomfort ausgeglichen.

\begin{figure}[H]
    \centering
    
    \caption*{Akku-Vergleich}
    \label{fig:Akku-Vergleich}
\end{figure}

Der Modellierprozess der 10. Version gliedert sich in sieben Schritte. Zunächst wird die grundlegende Biegung des Bügels in einer zweidimensionalen Skizze definiert (siehe Schritt 1 in Abbildung „Bügel v10: Arbeitsschritte der Konstruktion“) und anschließend nach oben extrudiert (Schritt 2). Aus der so entstandenen Fläche wird die seitliche Kontur (Schritt 3) des Bügels ausgeschnitten und anschließend verdickt (Schritt 4). Zur Vermeidung einer konstanten Breite über die gesamte Länge erfolgt abschließend eine weitere Formanpassung (Schritt 6) mittels einer zusätzlichen Skizze von oben (Schritt 5).

\begin{figure}[H]
    \centering
    
    \caption*{Bügel v10: Arbeitsschritte der Konstruktion}
    \label{fig:Bügel v10: Arbeitsschritte der Konstruktion}
\end{figure}

Schritt 7: Zur Aufbewahrung des Akkus wird der Bügel ausgehöhlt. Weiteres werden Einkerbungen für eine Abdeckung sowie eine Kabeldurchführung an der Vorderseite integriert. Abschließend wird der neue Scharniermechanismus umgesetzt, der aus zwei hohlen Kreisstrukturen an der oberen und unteren Ecke besteht.

\begin{figure}[H]
    \centering
    
    \caption*{Bügel v10: Letzter Konstruktionsschritt}
    \label{fig:Bügel v10: Letzter Konstruktionsschritt}
\end{figure}
  
\subsubsection*{Bügel v11 - 13}
In der elften Version wurde die Kabeldurchführung verkleinert, da sie zuvor überdimensioniert war. Außerdem wurde die Biegung des Bügels überarbeitet, da der äußere Winkel zu groß ausgefallen war und ein unangenehmes Aufsetzen der Brille verursachte.

Da das Endstück des Bügel v11-Modells zu dünn ausgeführt war, löste die zwölfte Version dieses Problem durch eine Anpassung der seitlichen Kontur.

In der dreizehnten Version wurde die Form des Bügels nur noch minimal verändert, insgesamt jedoch etwas dünner gestaltet.

\begin{figure}[H]
    \centering
    
    \caption*{Bügel v13: Seitenansicht}
    \label{fig:Bügel v13: Seitenansicht}
\end{figure}

\subsubsection*{Bügel v14 - finale Version}
Obwohl der äußere Winkel bereits reduziert wurde, war er nach wie vor zu eng für ein komfortables Aufsetzen der Brille, sodass die Biegung erneut angepasst werden musste:

\begin{figure}[H]
    \centering
    
    \caption*{Bügel v14: Biegungs-Skizze}
    \label{fig:Bügel v14: Biegungs-Skizze}
\end{figure}

\begin{figure}[H]
    \centering
    
    \caption*{Bügel v14: Oberansicht}
    \label{fig:Bügel v14: Oberansicht}
\end{figure}

Ein 3D-Druck dieser Version zeigte, dass der Bügel in allen vorgesehenen Aspekten den Anforderungen entsprach und ein komfortables Aufsetzen gewährleistete.
  
\section{Herausforderungen in der Entwicklung}
Die Realisierung eines kompakten, tragbaren Assistenzsystems, welches rechenintensive Machine-Learning-Prozesse mit kontinuierlicher Netzwerkkommunikation vereint, bringt diverse interdisziplinäre Herausforderungen mit sich. 

\subsection{Ressourcenlimits und Speicher-Fragmentierung (Software)}
Auf softwareseitiger Ebene stellte der extrem begrenzte Arbeitsspeicher (RAM) des Nicla Vision die größte Hürde dar. Die dynamische Speicherallokation in MicroPython führte bei der kontinuierlichen Bildverarbeitung wiederholt zur \textit{Heap-Fragmentierung}. Benötigte das FOMO-Modell anschließend einen zusammenhängenden Speicherblock für den Tensor, schlug die Allokation trotz ausreichendem Gesamtspeicher fehl. Die stringente Einführung der \textit{Zero-Copy}-Verfahren (\texttt{memoryview}), der Auslagerung auf den Flash-Speicher sowie die erzwungene Garbage-Collection lösten diese Instabilitäten endgültig.
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

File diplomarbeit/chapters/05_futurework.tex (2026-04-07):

% !TEX root = ../main.tex
\chapter{Ausblick}
Der aktuelle Prototyp des Assistenzsystems \glqq Ascenta\grqq\ belegt die Machbarkeit einer dezentralen, offline-fähigen Smart-Glasses-Architektur. Um das System jedoch von einem funktionalen Prototyp zu einem marktreifen Endkundenprodukt weiterzuentwickeln, sind in zukünftigen Iterationen verschiedene Erweiterungen und Optimierungen in allen Fachbereichen erforderlich.

\section{Software und Benutzeroberfläche}
Die zukünftige Software-Entwicklung muss sich primär auf die vollständige Barrierefreiheit und erweiterte Navigationskonzepte konzentrieren.

\subsection{Native Zero-UI-Applikation für blinde Nutzer}
Die aktuelle Android-Applikation verfügt über eine grafische Benutzeroberfläche (GUI), die essenziell für das Debugging, die Evaluierung und die Ersteinrichtung durch sehende Begleitpersonen ist. In einer finalen Version für den Endanwender muss diese App jedoch als reine Hintergrundanwendung (\textit{Zero-UI}) konzipiert werden. 

Das visuelle Interface wird dabei vollständig überflüssig. Die Applikation sollte sich nahtlos in native Accessibility-Dienste (wie Android TalkBack) integrieren und den Setup-Prozess (z.\,B. die Eingabe des WLAN-Passworts) über auditive Menüführung oder NFC-Tags abwickeln. Der Fokus liegt dabei auf maximaler Stabilität des Foreground-Services und einer Reduktion des Batterie- und Speicherverbrauchs des Smartphones, da keine visuellen Elemente gerendert werden müssen.

\subsection{Kontinuierliches auditives Raum-Feedback (Leitstrahl-Prinzip)}
Eine vielversprechende funktionale Erweiterung stellt die Implementierung eines dynamischen, akustischen Suchmodus dar. Sucht der Nutzer nach einem bestimmten Objekt (z.\,B. einem Stuhl oder einer Tür), könnte das System ein kontinuierliches Audiosignal generieren, das an die Funktion eines Geigerzählers oder eines Einparkhilfesensors angelehnt ist. Wenn der Nutzer den Kopf schwenkt und das gesuchte Objekt in das Sichtfeld der Kamera gerät, passt der Algorithmus die Frequenz (Tonhöhe) und das Intervall (Pings pro Sekunde) des Audiosignals in Echtzeit an. Je zentrierter das Objekt im Sichtfeld ist und je geringer die Distanz (gemessen durch den Time-of-Flight-Sensor) wird, desto intensiver wird das akustische Feedback. Dies würde blinden Nutzern eine hochpräzise, intuitive Zielführung ermöglichen, ohne sie mit komplexen, gesprochenen Sätzen zu überlasten.

\section{Künstliche Intelligenz und Modell-Training}

\subsection{Erweiterte Objekterkennung für Alltagsgegenstände}
\label{sec:future_ml_objects}
Derzeit ist das System auf die Erkennung von Personen optimiert. Für eine umfassende Alltagshilfe muss das zugrundeliegende Dataset massiv erweitert werden. Die Firmware und die App-Logik sind bereits so abstrahiert, dass sie beliebige Labels verarbeiten können. Zukünftige Iterationen müssen daher trainiert werden, um eine Vielzahl von Hindernissen und Zielen (z.\,B. Treppenstufen, Ampeln, Zebrastreifen, Türen, Sitzgelegenheiten oder herannahende Fahrzeuge) zuverlässig zu klassifizieren.

\subsection{Weiterentwicklung des Machine-Learning-Modells (Edge Impulse)}
\label{sec:future_edge_impulse}
Für mögliche Weiterentwicklungen dieses Projekts bietet sich ein grundlegender Wechsel der Hardware-Architektur an. Da die Umsetzung mit der Nicla Vision \cite{arduino_nicla_vision} die Leistungsgrenzen des Mikrocontrollers aufzeigte, steigert der Einsatz eines wesentlich leistungsfähigeren Prozessors in einer zukünftigen Version die Alltagsfähigkeit der Smart-Brille maßgeblich. Ein solches Hardware-Upgrade stellt die notwendigen Ressourcen bereit, um deutlich aufwendigere neuronale Netze auszuführen. Das System überwindet so die Limitierungen des aktuellen Modells und klassifiziert eine viel größere Anzahl unterschiedlicher Objekte gleichzeitig und präzise. Dadurch steigt der praktische Nutzen für den Anwender, da die Brille komplexe Umgebungen umfassender analysiert und versteht.

\section{Hardware und Elektronik}
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

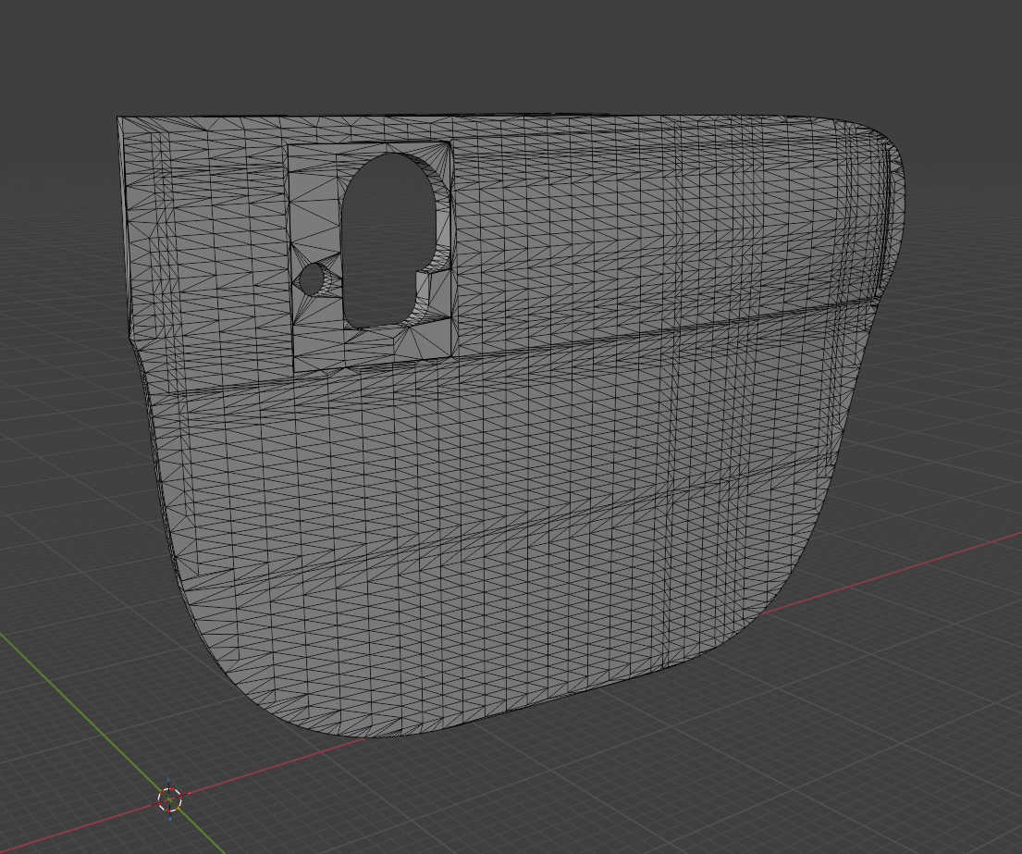
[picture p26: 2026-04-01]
diplomarbeit/media/images/Gläser-Abdeckung v3 - stl-File in Blender.png

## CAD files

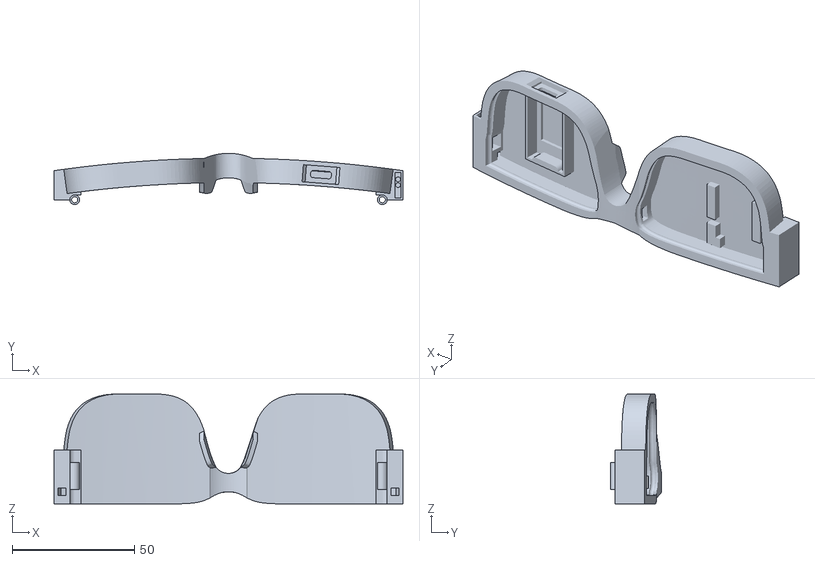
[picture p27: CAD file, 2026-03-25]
3D Models/Halterung v10.stl
142.8 x 21.0 x 45.0

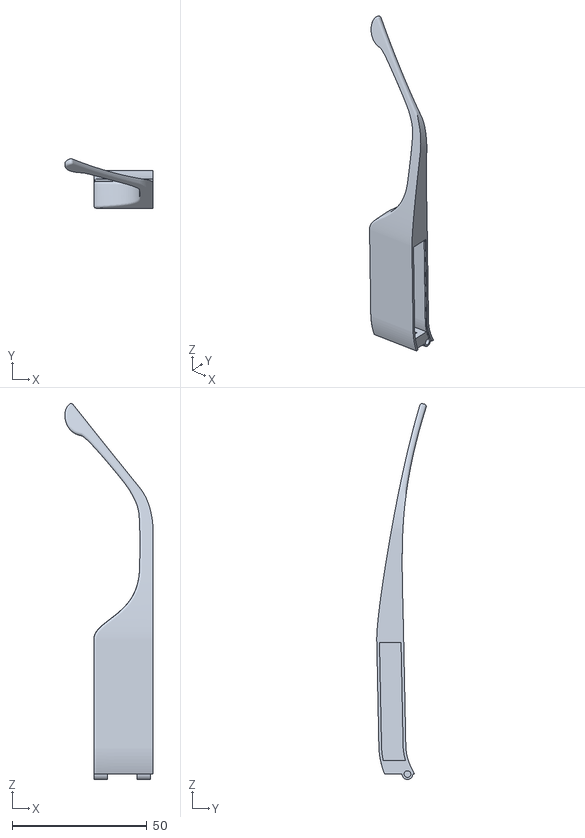
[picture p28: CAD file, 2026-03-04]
3D Models/Bügel v14.stl
32.7 x 18.4 x 139.3

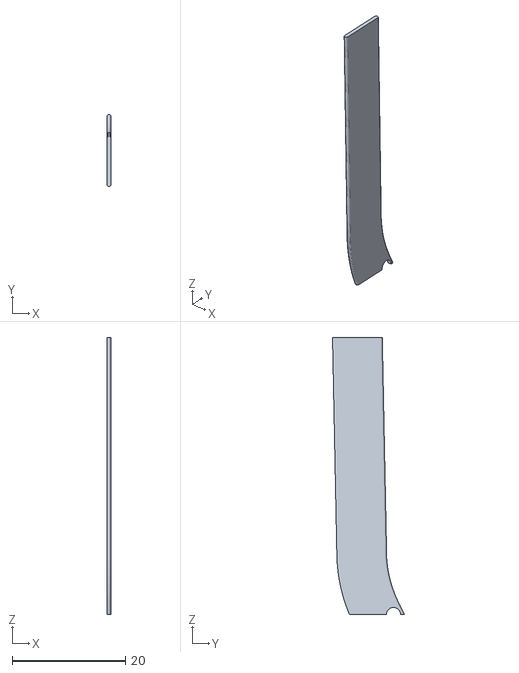
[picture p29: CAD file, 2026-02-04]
3D Models/Bügel-Abdeckung v2.stl
0.7 x 12.7 x 49.0

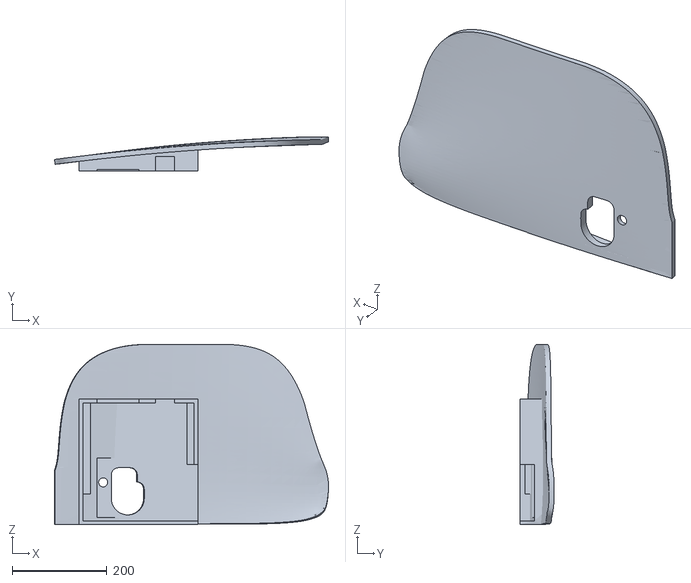
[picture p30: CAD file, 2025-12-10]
3D Models/Nicla (Halterung) v5.stl
577.5 x 72.5 x 380.0

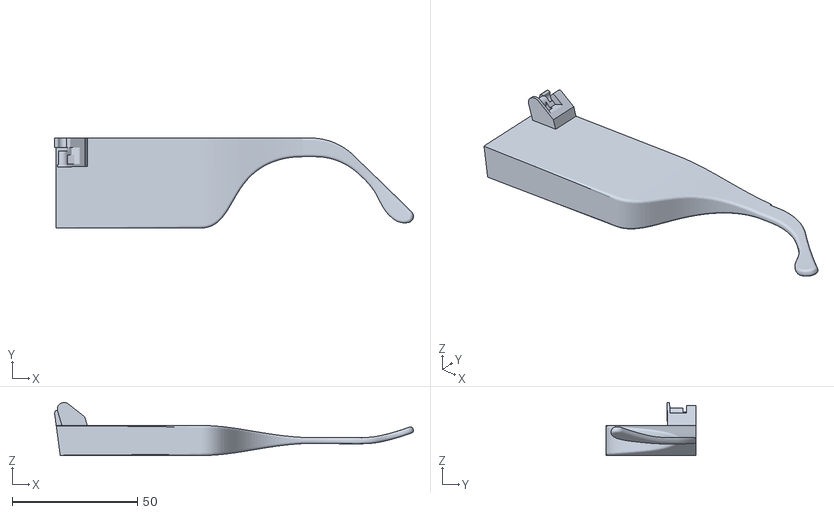
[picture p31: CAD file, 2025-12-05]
3D Models/Bügel v9 (links).stl
143.5 x 36.0 x 21.2

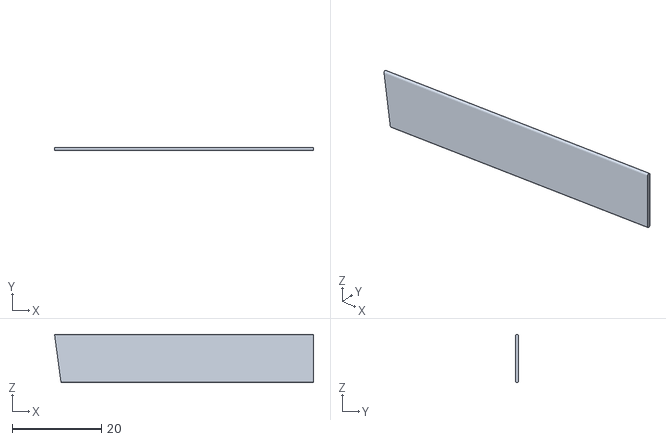
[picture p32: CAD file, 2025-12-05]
3D Models/Bügel-Abdeckung (links) v2.stl
57.9 x 0.7 x 10.8

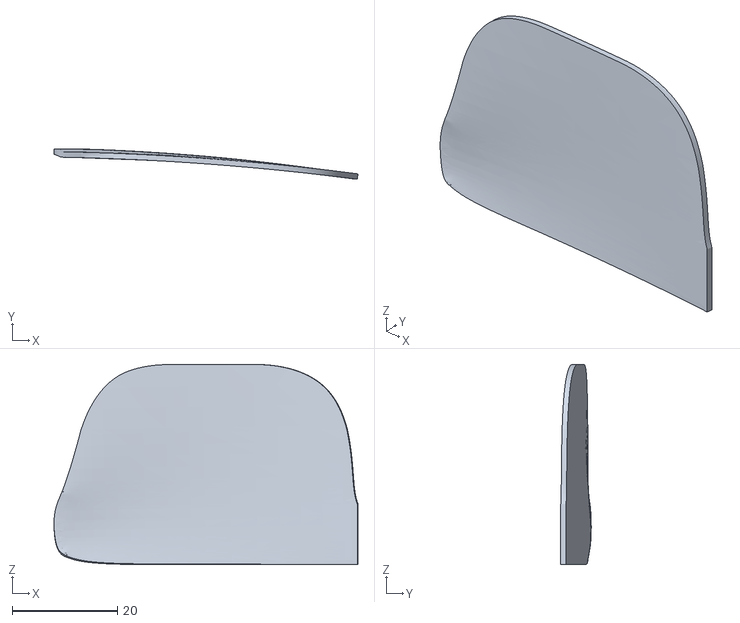
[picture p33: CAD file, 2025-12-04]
3D Models/Glas (rechts) v3.stl
57.7 x 5.80 x 38.0

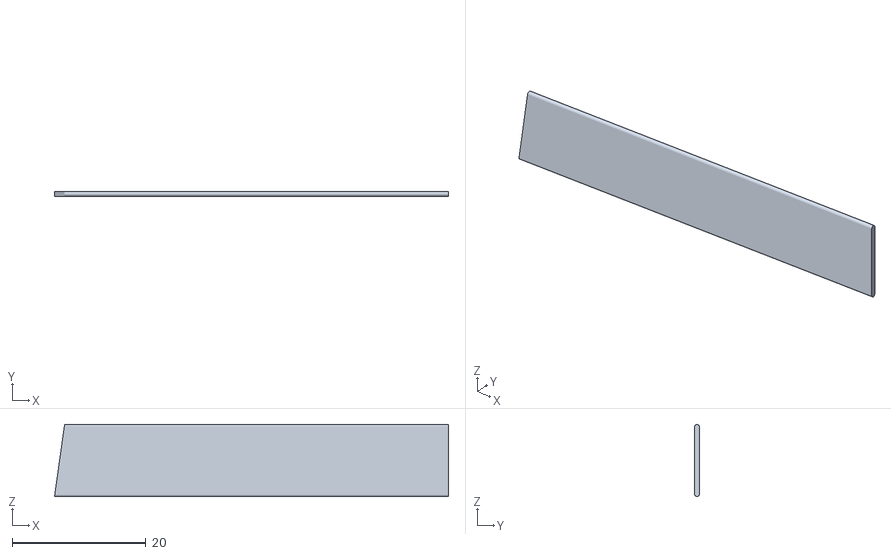
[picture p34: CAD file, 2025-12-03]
3D Models/Bügel-Abdeckung v1 (links).stl
58.9 x 0.7 x 10.8

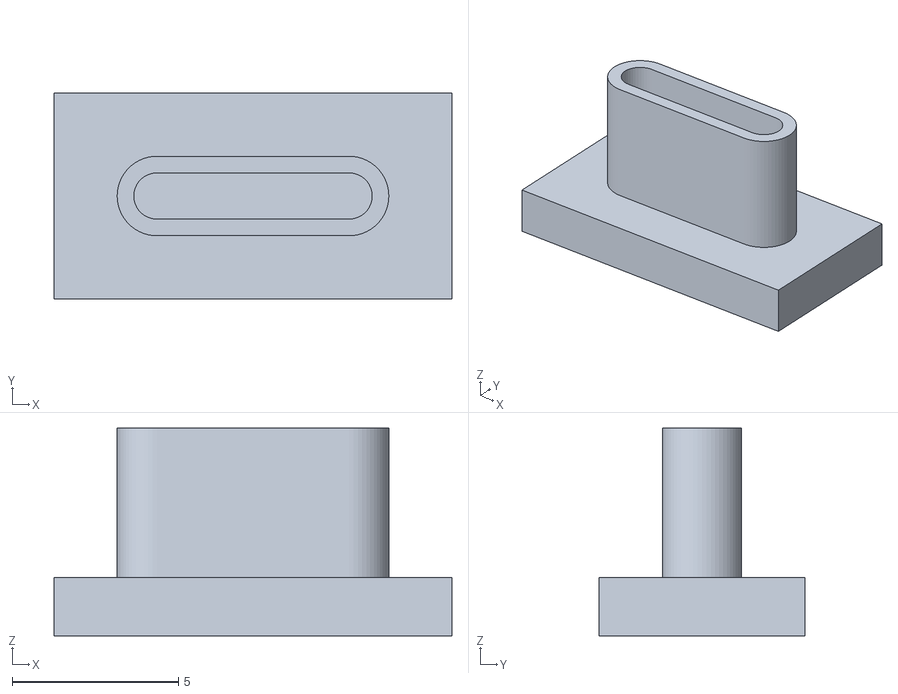
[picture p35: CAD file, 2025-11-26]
3D Models/USB-C (Cover) v2.stl
12.0 x 6.19 x 6.25

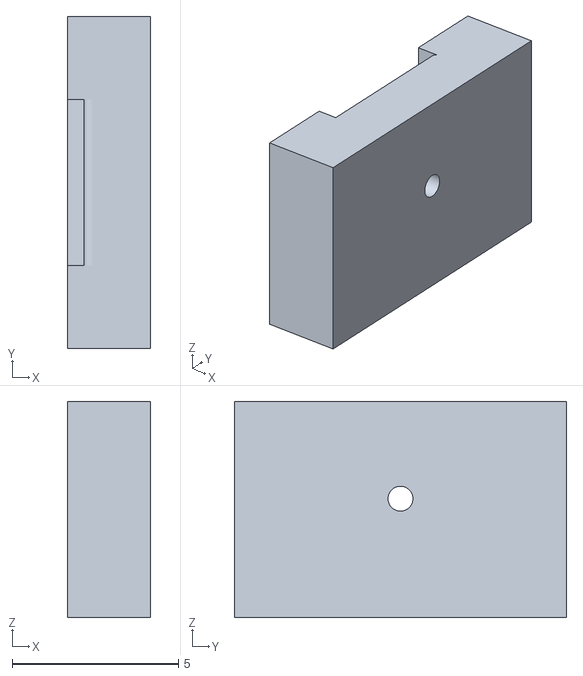
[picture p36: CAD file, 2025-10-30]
3D Models/Haken-Gegenstück v1.stl
2.50 x 10.0 x 6.50

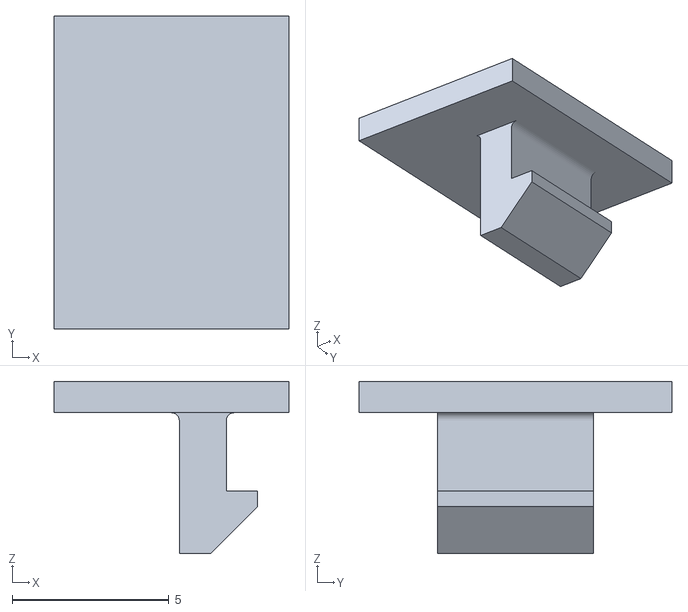
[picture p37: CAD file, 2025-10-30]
3D Models/Haken v1.stl
7.50 x 10.0 x 5.50

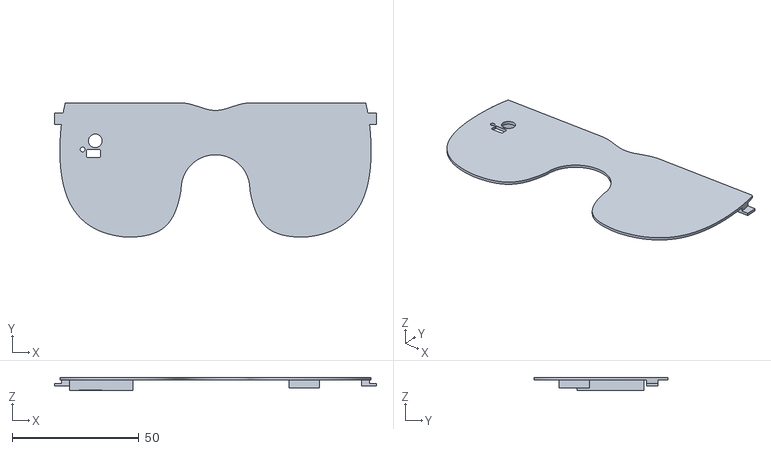
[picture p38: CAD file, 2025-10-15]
3D Models/Abdeckung v2.stl
127.0 x 53.0 x 5.25

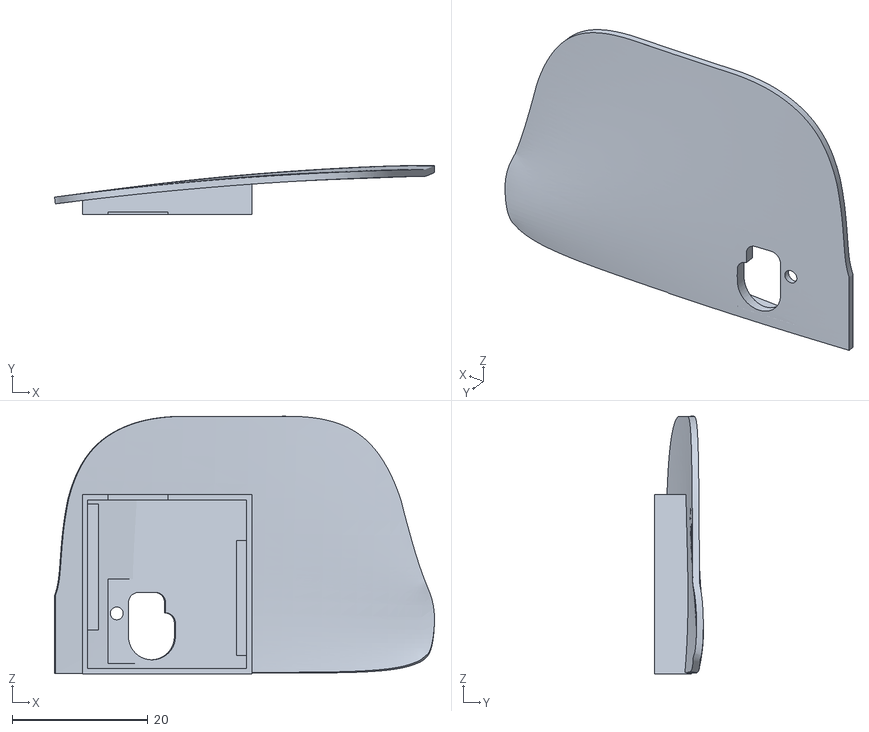
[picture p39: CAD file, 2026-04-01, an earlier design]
3D Models/Nicla (Halterung) v2.stl
56.1 x 7.21 x 38.0

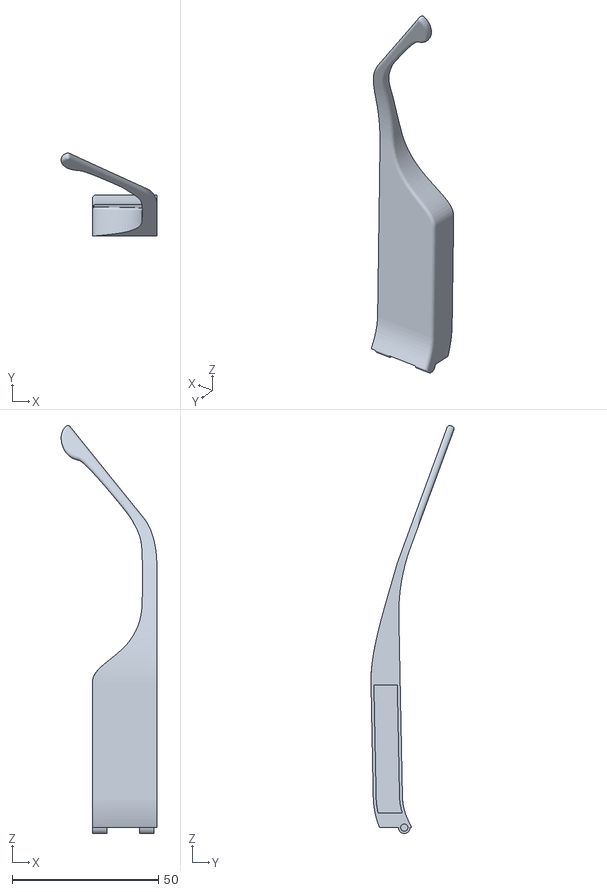
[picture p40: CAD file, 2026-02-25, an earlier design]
3D Models/Bügel v13.stl
32.7 x 28.4 x 139.6

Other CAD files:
3D Models/Bügel v9 (rechts).stl
3D Models/Bügel-Abdeckung (rechts) v2.stl
3D Models/Bügel-Abdeckung v1 (rechts).stl
3D Models/Halterung v9.stl
3D Models/Abdeckung v1.stl
3D Models/Bügel v1.stl
3D Models/Bügel v10.stl
3D Models/Bügel v11.stl
3D Models/Bügel v12.stl
3D Models/Bügel v2.stl
3D Models/Bügel v3 (links).stl
3D Models/Bügel v3 (rechts).stl
3D Models/Bügel v4.stl
3D Models/Bügel v5 (links).stl
3D Models/Bügel v5 (rechts).stl
3D Models/Bügel v6 (links).stl
3D Models/Bügel v6 (rechts).stl
3D Models/Bügel v7 (links).stl
3D Models/Bügel v7 (rechts).stl
3D Models/Bügel v8 (links).stl
3D Models/Bügel v8 (rechts).stl
3D Models/Glas (rechts) v2.stl
3D Models/Halterung v1.stl
3D Models/Halterung v2.stl
3D Models/Halterung v3.stl
3D Models/Halterung v4.stl
3D Models/Halterung v5.stl
3D Models/Halterung v6.stl
3D Models/Halterung v7.stl
3D Models/Halterung v8.stl
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

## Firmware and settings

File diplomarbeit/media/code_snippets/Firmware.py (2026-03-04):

import bluetooth
import network
import socket
import struct
import time
import sensor
import image
import gc
import uos
import audio
import micropython
import ml
import os
from machine import I2C, Pin, SPI
import vl53l1x
from lsm6dsox import LSM6DSOX
from pyb import LED

# Reserve memory for exceptions in interrupts
micropython.alloc_emergency_exception_buf(100)

led_red = LED(1)
led_green = LED(2)
led_blue = LED(3)

PROV_SERVICE_UUID = bluetooth.UUID("12345678-1234-5678-1234-567890ABCDEF")
SSID_CHAR_UUID    = bluetooth.UUID("12345678-1234-5678-1234-567890ABCDE1")
PASS_CHAR_UUID    = bluetooth.UUID("12345678-1234-5678-1234-567890ABCDE2")

UDP_IP = "255.255.255.255"
TCP_PORT = 5005
UDP_DISC_PORT = 5006

# Audio recording settings
REC_SECONDS = 2.5
SAMPLE_RATE = 16000
CHANNELS = 1
BYTES_PER_SAMPLE = 2
TOTAL_AUDIO_BYTES = int(SAMPLE_RATE * CHANNELS * BYTES_PER_SAMPLE * REC_SECONDS)
AUDIO_CHUNK_SIZE = 1024
NUM_AUDIO_CHUNKS = (TOTAL_AUDIO_BYTES // AUDIO_CHUNK_SIZE) + 1

FUEL_GAUGE_ADDR = 0x36

g_audio_chunks = []
g_audio_written = 0
g_ssid = ""
g_pass = ""
g_wifi_connected = False

class NiclaSystem:
    def __init__(self):
        self.server_sock = None
        self.tcp_conn = None
        self.last_broadcast = 0
        self.last_ml_print = time.ticks_ms()
        self.last_bat_check = 0
        self.wlan = None
        self.ble = bluetooth.BLE()
        self.ble.active(True)
        self.conn_handle = None
        self.req_image = False
        self.req_audio = False
        self.recording = False
        self.trigger_wifi_connect = False
        self.net = None
        self.labels = None
        self.tof = None
        self.lsm = None
        self.fuel_gauge_i2c = None
        self.sent_initial_bat = False
        self.low_bat_warned = False
        self.connection_time = 0

        # New IMU variables for Delta-Tap Detection
        self.last_tap_time = 0
        self.last_accel = (0, 0, 0)

        self._init_hardware()

        global g_audio_chunks
        try:
            gc.collect()
            g_audio_chunks = [bytearray(AUDIO_CHUNK_SIZE) for _ in range(NUM_AUDIO_CHUNKS)]
        except Exception as e:
            print("DEBUG [System]: CRITICAL - Audio chunks alloc failed:", e)

        saved = self._load_config()
        if saved:
            global g_ssid, g_pass
            g_ssid, g_pass = saved
            print("DEBUG [System]: Loaded saved WiFi config:", g_ssid)
            self.trigger_wifi_connect = True
        else:
            print("DEBUG [System]: No WiFi config found, starting BLE provisioning")
            self._setup_ble_provisioning()

    def _save_config(self, ssid, password):
        try:
            with open("wifi.txt", "w") as f:
                f.write(ssid + "\n")
                f.write(password)
        except Exception as e:
            print("DEBUG [System]: Save config failed:", e)

    def _load_config(self):
        try:
            with open("wifi.txt", "r") as f:
                lines = f.readlines()
                if len(lines) >= 2:
                    return lines[0].strip(), lines[1].strip()
        except: pass
        return None

    def _init_hardware(self):
        print("DEBUG [System]: Starting hardware init")

        try:
            sensor.reset()
            sensor.set_pixformat(sensor.RGB565)
            sensor.set_framesize(sensor.QVGA)
            sensor.set_windowing((240, 240))
            sensor.skip_frames(time=2000)
            print("DEBUG [System]: Sensor initialized (240x240 Window)")
        except Exception as e:
            print("DEBUG [System]: Sensor init failed:", e)

        try:
            i2c_bus = I2C(2)
            devices = i2c_bus.scan()
            print("DEBUG [I2C]: Scanned devices on Bus 2:", [hex(d) for d in devices])

            # Init ToF
            try:
                self.tof = vl53l1x.VL53L1X(i2c_bus)
                print("DEBUG [System]: ToF sensor initialized")
            except:
                print("DEBUG [System]: ToF init failed")
                self.tof = None

            # Init Fuel Gauge
            if FUEL_GAUGE_ADDR in devices:
                self.fuel_gauge_i2c = i2c_bus
                print("DEBUG [Fuel Gauge]: MAX17262 FOUND at 0x36!")
            else:
                print("DEBUG [Fuel Gauge]: MAX17262 NOT FOUND on Bus 2!")
        except Exception as e:
            print("DEBUG [System]: I2C Bus 2 init failed:", e)

        try:
            self.lsm = LSM6DSOX(SPI(5), cs=Pin("PF6", Pin.OUT_PP, Pin.PULL_UP))
            print("DEBUG [System]: IMU initialized")
        except: self.lsm = None

        try:
            audio.init(channels=CHANNELS, frequency=SAMPLE_RATE, gain_db=18)
            print("DEBUG [System]: Audio initialized")
        except: pass

        try:
            gc.collect()
            print("DEBUG [FOMO]: Loading trained.tflite...")
            self.net = ml.Model("trained.tflite", load_to_fb=True)
            print("DEBUG [FOMO]: Model successfully loaded!")

            self.labels = [line.rstrip('\n') for line in open("labels.txt")]
            print(f"DEBUG [FOMO]: Labels loaded: {self.labels}")
        except Exception as e:
            print("DEBUG [FOMO]: CRITICAL - Model loading failed! Exception:", e)

    def get_soc(self):
        if not self.fuel_gauge_i2c:
            return None
        try:
            data = self.fuel_gauge_i2c.readfrom_mem(FUEL_GAUGE_ADDR, 0x06, 2)
            soc_raw = int.from_bytes(data, 'little')
            soc = soc_raw / 256.0
            return soc
        except:
            return None

    def _setup_ble_provisioning(self):
        self.ble.irq(self._ble_irq)
        prov_svc = (PROV_SERVICE_UUID, ((SSID_CHAR_UUID, bluetooth.FLAG_WRITE), (PASS_CHAR_UUID, bluetooth.FLAG_WRITE)))
        handles = self.ble.gatts_register_services((prov_svc,))
        self.h_ssid, self.h_pass = handles[0][0], handles[0][1]
        self._advertise()

    def _advertise(self):
        adv = b'\x02\x01\x06' + struct.pack('<BB', 6, 0x09) + b"Nicla"
        self.ble.gap_advertise(100000, adv_data=adv)
        led_blue.on()

    def _ble_irq(self, event, data):
        global g_ssid, g_pass
        if event == 1: led_blue.off()
        elif event == 3:
            conn, v_h = data
            if v_h == self.h_ssid: g_ssid = self.ble.gatts_read(self.h_ssid).decode().strip()
            elif v_h == self.h_pass:
                g_pass = self.ble.gatts_read(self.h_pass).decode().strip()
                if g_ssid and g_pass:
                    self._save_config(g_ssid, g_pass)
                    self.trigger_wifi_connect = True

    def connect_wifi(self):
        global g_ssid, g_pass, g_wifi_connected
        print(f"DEBUG [System]: Connecting to WiFi: {g_ssid}")
        self.ble.active(False)
        led_blue.off()
        self.wlan = network.WLAN(network.STA_IF)
        self.wlan.active(True)
        self.wlan.connect(g_ssid, g_pass)

        for _ in range(15):
            if self.wlan.isconnected(): break
            led_red.on(); time.sleep_ms(100); led_red.off(); time.sleep_ms(900)

        if self.wlan.isconnected():
            g_wifi_connected = True
            led_green.on()
            print("DEBUG [System]: WiFi connected! IP:", self.wlan.ifconfig()[0])
            self._setup_tcp_server()
        else:
            print("DEBUG [System]: WiFi connection failed")
            try: uos.remove("wifi.txt")
            except: pass
            self.ble.active(True)
            self._setup_ble_provisioning()

    def _setup_tcp_server(self):
        try:
            if self.server_sock: self.server_sock.close()
        except: pass
        self.server_sock = socket.socket(socket.AF_INET, socket.SOCK_STREAM)
        self.server_sock.setsockopt(socket.SOL_SOCKET, socket.SO_REUSEADDR, 1)
        self.server_sock.bind(('', TCP_PORT))
        self.server_sock.listen(1)
        self.server_sock.setblocking(False)
        self.tcp_conn = None
        self.last_broadcast = 0
        print(f"DEBUG [System]: TCP-Server listening on port {TCP_PORT}")

    def manage_connection(self):
        if not self.tcp_conn:
            try:
                conn, addr = self.server_sock.accept()
                conn.setblocking(False)
                self.tcp_conn = conn
                self.req_image = False
                self.req_audio = False
                self.sent_initial_bat = False
                self.connection_time = time.ticks_ms()
                print("DEBUG [System]: App connected from", addr)
            except OSError:
                if time.ticks_diff(time.ticks_ms(), self.last_broadcast) > 2000:
                    try:
                        udp = socket.socket(socket.AF_INET, socket.SOCK_DGRAM)
                        udp.sendto(b"NICLA_READY", (UDP_IP, UDP_DISC_PORT))
                        udp.close()
                    except: pass
                    self.last_broadcast = time.ticks_ms()
            return False

        try:
            data = self.tcp_conn.recv(128)
            if data:
                cmds = data.decode('utf-8').strip().split('\n')
                for cmd in cmds:
                    c = cmd.strip()
                    if c == "take_picture": self.req_image = True
                    elif c == "RECORD": self.req_audio = True
                    elif c == "ping": self.send_tcp_packet(b"pong\n")
            else:
                self.tcp_conn.close()
                self.tcp_conn = None
        except OSError as e:
            if e.args[0] != 11:
                self.tcp_conn.close()
                self.tcp_conn = None
        return True

    def send_tcp_packet(self, data):
        if not self.tcp_conn: return
        self.tcp_conn.setblocking(True)
        try: self.tcp_conn.sendall(data)
        except:
            self.tcp_conn.close()
            self.tcp_conn = None
        finally:
            if self.tcp_conn: self.tcp_conn.setblocking(False)

    def check_imu(self):
        if not self.lsm or self.req_audio or self.req_image: return
        try:
            # Measure Delta-G (Jerk) instead of Absolute Force to ignore spinning
            x, y, z = self.lsm.accel()

            dx = abs(x - self.last_accel[0])
            dy = abs(y - self.last_accel[1])
            dz = abs(z - self.last_accel[2])

            # Save current for next frame
            self.last_accel = (x, y, z)

            delta_g = dx + dy + dz

            # A delta > 1.2g between 10ms frames is a hard, sudden physical tap.
            if delta_g > 1.75:
                now = time.ticks_ms()
                diff = time.ticks_diff(now, self.last_tap_time)

                if 100 < diff < 600:
                    print(f"DEBUG [IMU]: DOUBLE TAP! (Delta {delta_g:.2f}g)")
                    self.send_tcp_packet(b'{"action": "tap"}\n')
                    self.req_audio = True
                    self.last_tap_time = 0
                    time.sleep_ms(300)
                elif diff > 600:
                    print(f"DEBUG [IMU]: First tap detected... (Delta {delta_g:.2f}g)")
                    self.last_tap_time = now
                    time.sleep_ms(100)
        except: pass

    def run_active_detection(self):
        if not self.net: return
        if self.req_image or self.req_audio: return

        if self.tcp_conn and not self.sent_initial_bat:
            if time.ticks_diff(time.ticks_ms(), self.connection_time) > 2000:
                soc = self.get_soc()
                if soc is not None:
                    msg = '{"type": "battery", "soc": "%.1f"}\n' % soc
                    self.send_tcp_packet(msg.encode())
                self.sent_initial_bat = True

        now = time.ticks_ms()
        if self.tcp_conn and time.ticks_diff(now, self.last_bat_check) > 60000:
            self.last_bat_check = now
            soc = self.get_soc()
            if soc is not None:
                if soc <= 10.5 and not self.low_bat_warned:
                    msg = '{"type": "battery_warning", "soc": "%.1f"}\n' % soc
                    self.send_tcp_packet(msg.encode())
                    self.low_bat_warned = True
                elif soc > 15.0:
                    self.low_bat_warned = False

        debug_print = False
        if time.ticks_diff(now, self.last_ml_print) > 3000:
            self.last_ml_print = now
            debug_print = True

        try:
            img = sensor.snapshot()
            distance_mm = 0
            if self.tof:
                try: distance_mm = self.tof.read()
                except: pass

            try:
                raw_output = self.net.predict([img])
                heatmap = raw_output[0]
                shape = heatmap.shape

                best_label, best_conf, best_x, best_y = None, 0.0, 0, 0

                if len(shape) == 4:
                    grid_y, grid_x, classes = shape[1], shape[2], shape[3]
                    cell_w, cell_h = img.width() / grid_x, img.height() / grid_y

                    for y in range(grid_y):
                        for x in range(grid_x):
                            for c in range(1, classes):
                                score = heatmap[0][y][x][c]
                                if score > 0.45 and score > best_conf:
                                    best_conf = score
                                    best_x = int(x * cell_w + (cell_w / 2))
                                    best_y = int(y * cell_h + (cell_h / 2))
                                    if self.labels and c < len(self.labels): best_label = self.labels[c]
                                    else: best_label = f"Class_{c}"

                if best_label:
                    json_str = '{"label": "%s", "conf": "%.2f", "dist": "%d", "x": "%d", "y": "%d"}\n' % (best_label, best_conf, distance_mm, best_x, best_y)
                    self.send_tcp_packet(json_str.encode())

            except ValueError as ve:
                pass
            except Exception as e:
                pass
            finally:
                gc.collect()

        except Exception as e:
            pass

    def process_image(self):
        self.req_image = False
        led_blue.on()
        path = "temp.jpg"
        try:
            img = sensor.snapshot()
            img.save(path, quality=40)
            del img
            gc.collect()
            size = os.stat(path)[6]
            self.send_tcp_packet(f"IMG_START:{size}\n".encode())
            with open(path, 'rb') as f:
                while True:
                    chunk = f.read(1024)
                    if not chunk: break
                    self.send_tcp_packet(chunk)
            uos.remove(path)
        except: pass
        led_blue.off()
        gc.collect()

    def process_audio(self):
        led_red.on()
        global g_audio_chunks, g_audio_written
        gc.collect()
        try:
            self.rec_idx = 0
            self.rec_offset = 0
            g_audio_written = 0
            self.recording = True
            audio.start_streaming(self._audio_callback)
            while self.recording: time.sleep_ms(10)
            audio.stop_streaming()
            led_red.off()
            led_blue.on()

            total_len = 44 + g_audio_written
            self.send_tcp_packet(f"AUD_START:{total_len}\n".encode())

            header = struct.pack('<4sI4s4sIHHIIHH4sI', b'RIFF', 36+g_audio_written, b'WAVE', b'fmt ', 16, 1, CHANNELS, SAMPLE_RATE, SAMPLE_RATE*CHANNELS*BYTES_PER_SAMPLE, CHANNELS*BYTES_PER_SAMPLE, 16, b'data', g_audio_written)
            self.send_tcp_packet(header)

            count_to_send = min(self.rec_idx + 1, len(g_audio_chunks))
            for i in range(count_to_send):
                chunk = g_audio_chunks[i]
                if not chunk: continue
                length = AUDIO_CHUNK_SIZE if i != self.rec_idx else self.rec_offset
                if length > 0:
                    mv = memoryview(chunk)[:length]
                    off = 0
                    while off < length:
                        end = min(off + 1024, length)
                        self.send_tcp_packet(mv[off:end])
                        off = end
        except: pass
        finally:
            self.req_audio = False
            led_red.off()
            led_blue.off()
            gc.collect()

    def _audio_callback(self, buf):
        global g_audio_written
        if not self.recording: return
        mv = memoryview(buf)
        l = len(mv)
        off = 0
        while l > 0:
            if self.rec_idx >= len(g_audio_chunks): self.recording = False; break
            chunk = g_audio_chunks[self.rec_idx]
            space = AUDIO_CHUNK_SIZE - self.rec_offset
            amt = min(l, space)
            chunk[self.rec_offset : self.rec_offset+amt] = mv[off : off+amt]
            self.rec_offset += amt
            off += amt
            l -= amt
            g_audio_written += amt
            if self.rec_offset >= AUDIO_CHUNK_SIZE:
                self.rec_idx += 1
                self.rec_offset = 0
        if g_audio_written >= TOTAL_AUDIO_BYTES: self.recording = False

nicla = NiclaSystem()
while True:
    if nicla.trigger_wifi_connect:
        nicla.trigger_wifi_connect = False
        nicla.connect_wifi()

    if g_wifi_connected:
        if not nicla.wlan.isconnected():
            led_green.off()
            g_wifi_connected = False
            nicla.ble.active(True)
            nicla._advertise()
        else:
            is_connected = nicla.manage_connection()
            if is_connected:
                nicla.check_imu()
                if nicla.req_image:
                    nicla.process_image()
                elif nicla.req_audio:
                    nicla.process_audio()
                else:
                    nicla.run_active_detection()
    time.sleep_ms(10)

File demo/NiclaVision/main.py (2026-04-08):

import bluetooth, network, socket, struct, time, sensor, image, gc, uos, audio, micropython, ml, os
from machine import I2C, Pin, SPI
import vl53l1x
from lsm6dsox import LSM6DSOX
from pyb import LED

micropython.alloc_emergency_exception_buf(100)
led_red, led_green, led_blue = LED(1), LED(2), LED(3)

TCP_PORT, UDP_DISC_PORT = 5005, 5006
UDP_IP = "255.255.255.255"
REC_SECONDS, SAMPLE_RATE = 2.5, 16000
TOTAL_AUDIO_BYTES = int(SAMPLE_RATE * 1 * 2 * REC_SECONDS)
AUDIO_CHUNK_SIZE = 1024
NUM_AUDIO_CHUNKS = (TOTAL_AUDIO_BYTES // AUDIO_CHUNK_SIZE) + 1
FUEL_GAUGE_ADDR = 0x36

TOF_WARN_DIST = 1500
TOF_ALERT_DIST = 800
TOF_CRITICAL_DIST = 400
TOF_POLL_MS = 150

PROV_SERVICE_UUID = bluetooth.UUID("12345678-1234-1234-1234-123456789abc")
SSID_CHAR_UUID = bluetooth.UUID("12345678-1234-1234-1234-123456789abd")
PASS_CHAR_UUID = bluetooth.UUID("12345678-1234-1234-1234-123456789abe")

g_audio_chunks = []
g_audio_written = 0
g_wifi_connected = False
g_ssid, g_pass = "", ""

class NiclaSystem:
    def __init__(self):
        self.server_sock = None
        self.tcp_conn = None
        self.last_broadcast = 0
        self.last_bat_check = 0
        self.wlan = None
        self.ble = bluetooth.BLE()
        self.ble.active(True)
        self.req_image = False
        self.req_audio = False
        self.recording = False
        self.trigger_wifi_connect = False
        self.net = None
        self.labels = None
        self.tof = None
        self.lsm = None
        self.fuel_gauge_i2c = None
        self.sent_initial_bat = False
        self.low_bat_warned = False
        self.connection_time = 0
        self.last_tap_time = 0
        self.tap_count = 0
        self.tap_settle_time = 0
        self.last_accel = (0, 0, 0)
        self.last_tof_poll = 0
        self.last_tof_zone = "clear"

        self._init_hardware()

        global g_audio_chunks
        try:
            gc.collect()
            g_audio_chunks = [bytearray(AUDIO_CHUNK_SIZE) for _ in range(NUM_AUDIO_CHUNKS)]
            print("DEBUG [Audio]: Buffer allocated")
        except: print("DEBUG [Audio]: Alloc Failed")

        saved = self._load_config()
        if saved:
            global g_ssid, g_pass
            g_ssid, g_pass = saved
            self.trigger_wifi_connect = True
        else: self._setup_ble_provisioning()

    def _init_hardware(self):
        print("DEBUG [System]: Init Start")
        try:
            sensor.reset()
            sensor.set_pixformat(sensor.RGB565)
            sensor.set_framesize(sensor.QVGA)
            sensor.set_windowing((240, 240))
            sensor.skip_frames(time=2000)
            print("DEBUG [Sensor]: OK")
        except: print("DEBUG [Sensor]: FAIL")

        try:
            i2c_bus = I2C(2)
            scan = i2c_bus.scan()
            if 0x29 in scan:
                self.tof = vl53l1x.VL53L1X(i2c_bus) # Basic OpenMV driver
                print("DEBUG [ToF]: OK")
            if FUEL_GAUGE_ADDR in scan:
                self.fuel_gauge_i2c = i2c_bus
                print("DEBUG [Fuel]: OK")
        except: print("DEBUG [I2C]: FAIL")

        try:
            self.lsm = LSM6DSOX(SPI(5), cs=Pin("PF6", Pin.OUT_PP, Pin.PULL_UP))
            print("DEBUG [IMU]: OK")
        except: self.lsm = None

        try:
            audio.init(channels=1, frequency=SAMPLE_RATE, gain_db=24)
            self.net = ml.Model("trained.tflite", load_to_fb=True)
            self.labels = [line.rstrip('\n') for line in open("labels.txt")]
            print("DEBUG [ML]: OK")
        except: print("DEBUG [ML]: FAIL")

    def get_soc(self):
        if not self.fuel_gauge_i2c: return None
        try:
            v_raw = self.fuel_gauge_i2c.readfrom_mem(FUEL_GAUGE_ADDR, 0x09, 2)
            voltage = int.from_bytes(v_raw, 'little') * 0.000078125
            s_raw = self.fuel_gauge_i2c.readfrom_mem(FUEL_GAUGE_ADDR, 0x06, 2)
            soc = int.from_bytes(s_raw, 'little') / 256.0
            if voltage > 4.15: soc = 100.0 # Full charge calibration
            return soc
        except: return None

    def check_imu(self):
        if not self.lsm or self.req_audio or self.req_image: return
        try:
            x, y, z = self.lsm.accel()
            dz = abs(z - self.last_accel[2])
            self.last_accel = (x, y, z)
            now = time.ticks_ms()

            # Resolve pending tap gesture after settle window
            if self.tap_count > 0 and time.ticks_diff(now, self.last_tap_time) > 600:
                if self.tap_count == 1: # Double Tap
                    print("DEBUG [IMU]: RECORDING")
                    self.req_audio = True
                elif self.tap_count >= 2: # Triple Tap
                    print("DEBUG [IMU]: BATTERY")
                    soc = self.get_soc()
                    msg = '{"type":"bat_status","soc":"%.1f"}\n' % (soc if soc else 0)
                    self.send_tcp_packet(msg.encode())
                self.tap_count = 0

            if dz > 4.5: # Hard tap detection
                print(f"DEBUG [IMU]: Spike {dz:.2f}")
                diff = time.ticks_diff(now, self.last_tap_time)
                if 100 < diff < 600:
                    self.tap_count += 1
                else:
                    self.tap_count = 0
                self.last_tap_time = now
        except Exception as e: print("DEBUG [IMU]: Error", e)

    def check_tof(self):
        if not self.tof or self.req_image or self.req_audio: return
        now = time.ticks_ms()
        if time.ticks_diff(now, self.last_tof_poll) < TOF_POLL_MS: return
        self.last_tof_poll = now
        try:
            dist = self.tof.read()
            if dist <= 0 or dist > 8000: return  # Out of range / bad read

            if dist <= TOF_CRITICAL_DIST:
                zone = "critical"
            elif dist <= TOF_ALERT_DIST:
                zone = "alert"
            elif dist <= TOF_WARN_DIST:
                zone = "warning"
            else:
                zone = "clear"

            if zone != self.last_tof_zone:
                self.last_tof_zone = zone
                if zone != "clear":
                    msg = '{"type":"collision","dist":%d,"zone":"%s"}\n' % (dist, zone)
                    print(f"DEBUG [ToF]: {zone} at {dist}mm")
                    self.send_tcp_packet(msg.encode())
                else:
                    self.send_tcp_packet(b'{"type":"collision","dist":0,"zone":"clear"}\n')
        except Exception as e: print("DEBUG [ToF]: Error", e)

    def run_active_detection(self):
        if not self.net or self.req_image or self.req_audio: return
        now = time.ticks_ms()

        if self.tcp_conn:
            if not self.sent_initial_bat and time.ticks_diff(now, self.connection_time) > 2000:
                soc = self.get_soc()
                if soc: self.send_tcp_packet(('{"type":"bat_init","soc":"%.1f"}\n'%soc).encode())
                self.sent_initial_bat = True
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

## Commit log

2025-10-01 Added Prototypes
    [Prototyp_0.1.stl, Prototyp_0.2.stl]
2025-10-15 Create Interrupt
2025-10-22 Create Button 0_1
2025-10-22 Refactor BLEPeripheral and button interrupt handling
    Refactor BLE peripheral class and improve button handling.
2026-02-04 Rename Bügel v10 (links).stl to Bügel v10.stl
    [Bügel v10.stl]
2026-02-13 Current State of Nicla Vision Software
    WiFi not implemented yet, running on BLE with local STT on the App side
2026-02-19 Moved old app to Ascenta-old
    Since changing the architecture to wifi and to keep track of the old app properly I moved it to the old folder to keep pushing onto the new app ontop.
2026-03-04 Rename Bügel_v13.stl to Bügel v13.stl
    [Bügel v13.stl]
2026-03-27 current State
2026-04-08 Refactor main.py for improved readability and functionality
    Consolidate import statements, refactor variable assignments, and improve error handling. Update BLE provisioning and WiFi connection methods for better readability and functionality.
    [main.py]
